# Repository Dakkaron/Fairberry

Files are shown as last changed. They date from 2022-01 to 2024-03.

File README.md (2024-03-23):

# Fairberry

The goal of this project is to add a BlackBerry Q10 keyboard to non-BlackBerry phones. While this can easily be adapted to suit any other phone with an USB port at the bottom, I will focus on releasing files for the Fairphone 4, since that is what I have. Feel free to adjust it to your phone and share your results in the discussion area.

The Fairberry keyboard is detachable and can be used without any modifications on the phone. Since it connects over USB, there is no need for separate batteries or glitchy Bluetooth connections.

## What can you expect?

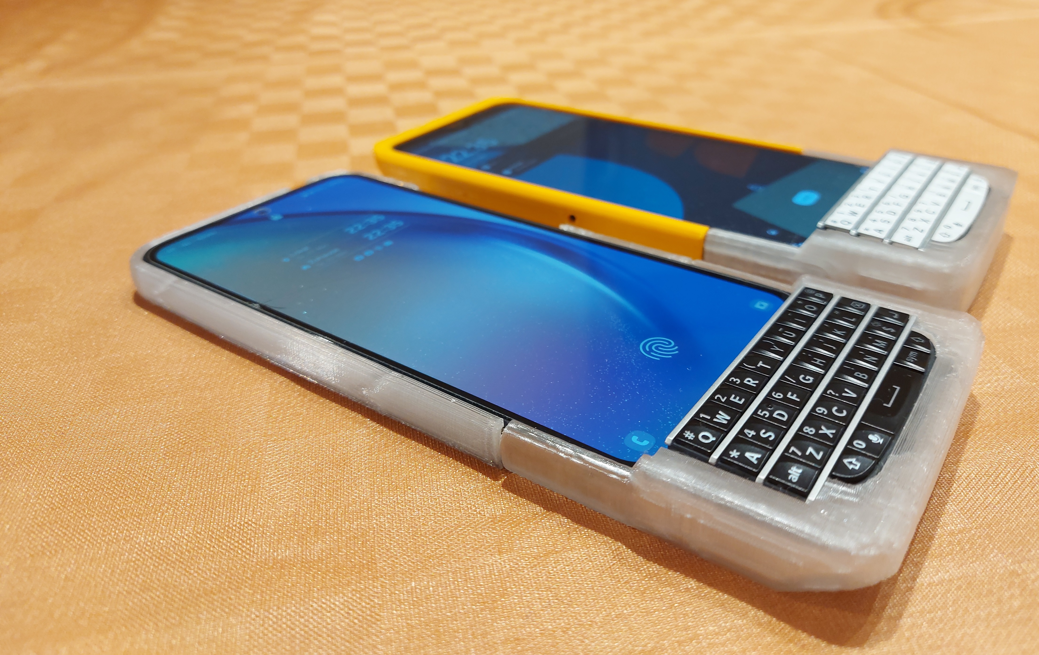
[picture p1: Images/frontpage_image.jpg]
Samsung Galaxy A54 and Fairphone 4 with Fairberry keyboards


### Demo video
Demo video showing the functionality of the Fairberry keyboard (https://www.youtube.com/watch?v=iDb8_ld9gOQ)

## How to build it?

Recommended: [Custom mainboard](https://github.com/Dakkaron/Fairberry/blob/main/Documentation/Hardware_Fairberry_Mainboard.md)

[Old Arduino-based hardware](https://github.com/Dakkaron/Fairberry/blob/main/Documentation/Hardware_Arduinobased.md)

## How to use it?

[Key combinations and apps](https://github.com/Dakkaron/Fairberry/blob/main/Documentation/UX_Shortcuts_and_Apps.md)

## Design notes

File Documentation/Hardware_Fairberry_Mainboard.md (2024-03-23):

# Bill of Materials

- Blackberry Q10 replacement keyboard
- Assembled mainboard from JLCPCB
- Solderable USB 2.0 OTG connector (can be USB C, Micro USB or even Lightning)
- Thin wires to connect the USB board to the PCB (The thinner the better)
- 6 Pin headers
- USBASP Programmer
- Jumper wires

# Ordering from JLCPCB

## Downloads

First go to the release page (https://github.com/Dakkaron/Fairberry/releases) and locate the newest release.

Download gerber-*.zip, BOM.xlsx and CPL.xlsx.

## Order Hirose Keyboard Connector

JLCPCB does not usually stock the keyboard connector (Hirose BM14B(0.8)-24DS-0.4V(53)). To get them to include this part in the assembly, you first need to order the part in their part sourcing programme. To do so:

- Head to the part ordering page: https://jlcpcb.com/parts
- Log in to your JLCPCB account (create one if you don't have one)
- At the part ordering page, search for this part: HRS(Hirose) BM14B(0.8)-24DS-0.4V(53)
- There should be one result. Select it, choose an amount (2 or multiples of 5) and then press "Add to My Part Lib" and follow the order process
- Sourcing the components will take a few weeks
- Once they sourced the parts, they will refund you the difference between what you paid and what JLCPCB paid to the part seller, so it will likely be a bit cheaper than what you paid up front

## Order PCB

- Head to the JLCPCB PCB ordering page: https://cart.jlcpcb.com/quote?orderType=1&stencilLayer=2&stencilWidth=100&stencilLength=100&stencilCounts=5
- Upload the gerber-*.zip file. You can leave everything in the main box on default.
- Scroll down until you find "PCB Assembly" and activate that.
- Depending on how many parts you want to order, select 2 or 5 under "PCB Assembly". Ordering more parts will be cheaper per part. Please note, you will receive 5 boards regardless, but only the selected amount will be populated (will have components soldered to it).
- Press "Next".

## BOM and CPL

On the following page, upload the BOM.xmlx and the CPL.xmlx. On the dropdown on the bottom of the page select "Office Appliance and Accessories" -> "Keyboard".

Press "Next" again.

## Component list

You should now see a list of components. Verify that no errors (e.g. "Component out of stock") are displayed and all parts are selected. You should be able to take the Hirose connector from your part library.

Press "Next" again.

## Component placement

The next page shows a rendering of the component placement. Verify (multiple times) that the image looks exactly as the image below. Especially all the pink markings need to be exactly the same.

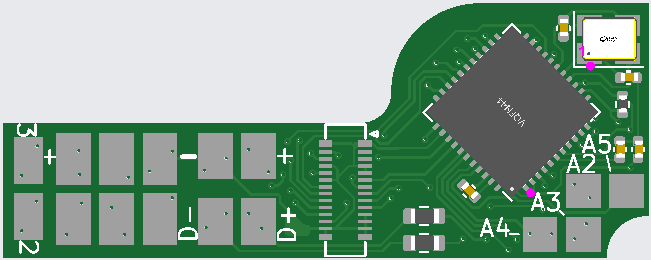
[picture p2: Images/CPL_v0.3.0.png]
Component placement image


If one of the parts is rotated wrong (indicated by the pink markings being in the wrong location), select the component and use the "All Rotate Right/Left" buttons at the top to fix it.

If you are really sure it looks the same, press "Save to cart" and procede with ordering the PCB.

# Remaining Assembly

Solder the programming headers like in the picture below. These pin headers are only required for initial flashing, and can be desoldered afterwards, as they won't be needed anymore.

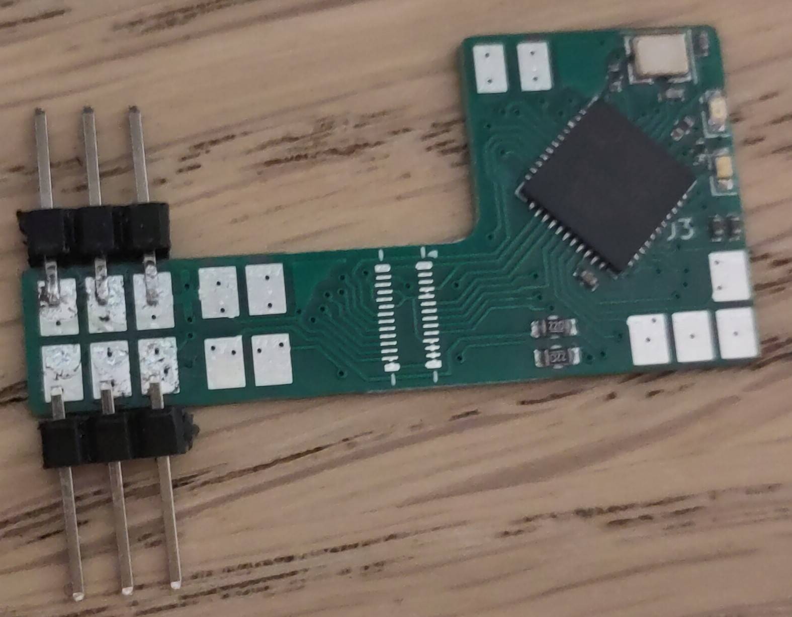
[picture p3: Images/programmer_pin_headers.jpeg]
Placement of programming pin headers


Now take your USBASP and some jumper wires and connect the headers to the fitting pins on the programmer, following the images below. The pinout of the USBASP is shown here as viewed into the connector, with no cable plugged in.

Make sure you are using pinout for the right mainboard version.

## USBASP
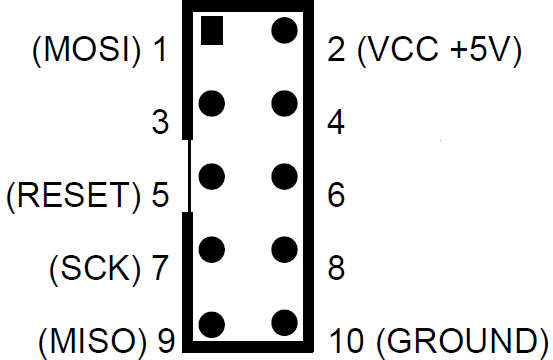
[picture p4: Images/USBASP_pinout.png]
USBASP pinout


## v0.1.1
![]()
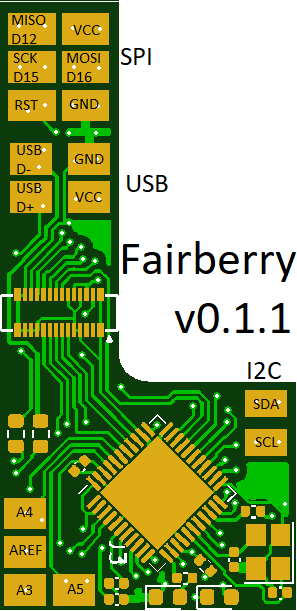
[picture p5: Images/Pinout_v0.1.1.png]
Fairberry v0.1.1 pinout


## v0.2.0
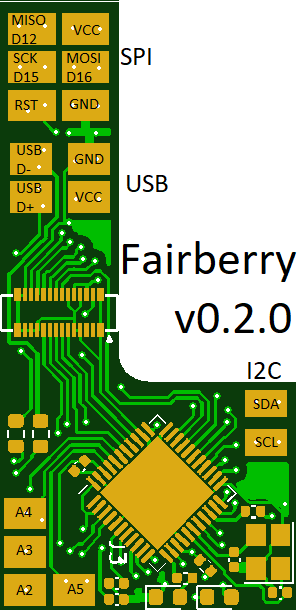
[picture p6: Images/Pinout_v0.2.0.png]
Fairberry v0.2.0 pinout


## v0.3.0
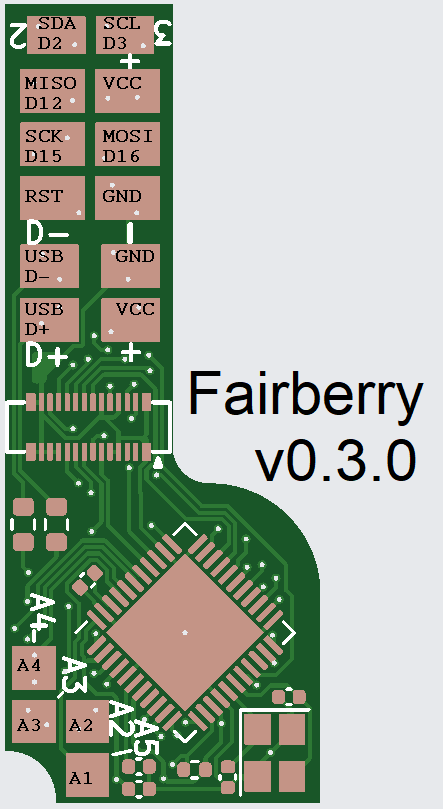
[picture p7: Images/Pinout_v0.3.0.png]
Fairberry v0.3.0 pinout


Now solder the USB connector to the USB port on the Fairberry mainboard. Take care to get the pinout right and not cause any shorts.

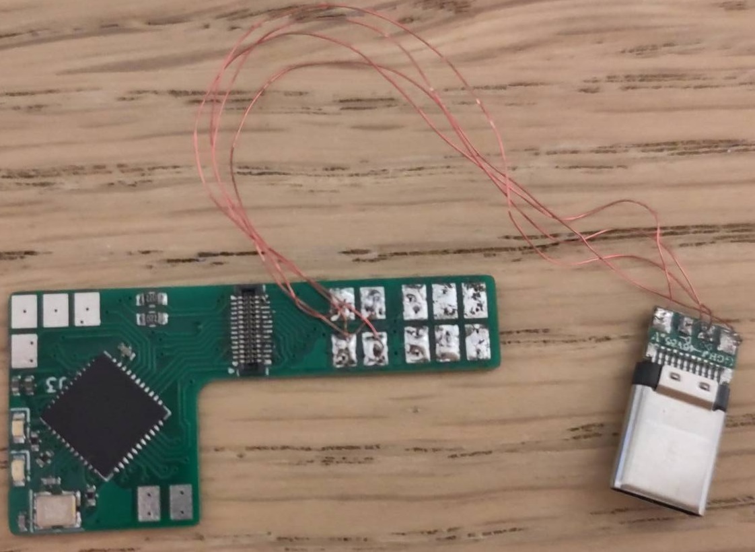
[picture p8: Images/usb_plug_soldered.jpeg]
Fairberry v0.1.1 with USB connector


# Flashing the firmware

## Flashing the bootloader

This step only needs to be done once. After you flashed the bootloader, you can update the firmware over the USB connector.

Download and install the [Arduino IDE](https://www.arduino.cc/en/software).

Open the Arduino IDE.

Connect the USBASP with the connected Fairberry Mainboard to a USB port of the computer.

WARNING: DO NOT PLUG THE USB CONNECTOR OF THE FAIRBERRY INTO THE PC, WHILE THE USBASP IS CONNECTED!

In the Arduino IDE, select "Tools" -> "Board" -> "Arduino AVR Boards" -> "Arduino Leonardo". Then select "Tools" -> "Burn Bootloader".

This will take a while. Wait until it finishes. If there are errors, check your solder joints and the wires connecting the Fairberry to the USBASP.

Once this is done, disconnect the Fairberry from the USBASP. You can now desolder the header pins.

## Flashing the firmware

Head to the [releases page](https://github.com/Dakkaron/Fairberry/releases), download and unzip the file BBQ10_Arduino_sources.zip.

Open the BBQ10.ino in the Arduino IDE.

In the Arduino IDE select "Tools" -> "Manage Libraries".

In the Library Manager, check that the following libraries are installed (and install them if they aren't):

- Keyboard, by Arduino, version 1.0.4 or newer
- LowPower_LowPowerLab, by LowPowerLab, version 2.2.0 or newer.

Now close the Library Manager.

Open the file configuration.h in the Arduino IDE.

Find this line

    #define BOARD_TYPE FAIRBERRY_V0_3_0

and adjust the board type to the version that you are using.

Make sure the USBASP is disconnected from the PC and the Fairberry Mainboard.

Connect the Fairberry Mainboard's USB connector to the PC.

Select "Sketch" -> "Upload" and wait for the upload to finish.

If you get an error, verify your soldering.

# Testing

Now you are basically done. To test the mainboard, connect the Blackberry Q10 keyboard to the connector and plug the whole thing into the USB/Lightning port of your phone. Open some app where you can type and check if every key works as expected.

## Troubleshooting

If some keys work but others don't, some of the pins on the Hirose connector aren't soldered correctly. To figure out which ones, check out this [Column to row key matrix](https://github.com/arturo182/BBQ10KBD#columnrow-to-key-matrix).  With this you can figure out, which rows/colums have bad contacts.

Now look at this [breakout adapter](https://github.com/arturo182/bbq10kbd_breakout) and follow the traces from the defective row/column pin to the pin on the connector to figure out, which pin has a bad contact.

If you know which pin is at fault, try to carefully solder it on with a fine-tipped soldering iron.

## Generating the 3D-print file for the case

### Prerequisites
- Install [OpenSCAD](https://openscad.org/)
- Download and extract the Source Code zip file from [the newest release](https://github.com/Dakkaron/Fairberry/releases)
- Open `Fairberry-x.x.x/Case/Generator/Fairberry.scad` in OpenSCAD

### Customizing
- In the `Fairberry.scad` script, set the `SCREEN_PROTECTOR_HEIGHT` to the thickness of your screen protector. If you don't use one, set it to `0`.
- Set the `EXTRUSION_WIDTH` to the extrusion width of your 3D printer. For 0.4mm nozzles, it's usually 0.48. If you use a resin printer, leave it at 0.4.
- If you are using a Fairphone 4 or a Samsung Galaxy A54, comment out the line `include <presets/Custom.scad>` by placing a double slash (`//`) at the beginning of the line, and uncomment the line fitting your phone. You can skip the rest of the customization.
- If you are using a different phone, open up `Fairberry-x.x.x/Case/Generator/presets/Custom.scad` in OpenSCAD and customize the values in there to your liking. To preview the changes, save your changes in the `Custom.scad` and then open up `Fairberry.scad` in OpenSCAD and press F5 to generate a preview.
- When using `Custom.scad`, it is recommended to find a dummy STL of your phone. [Yeggi.com](https://www.yeggi.com/) and [Grabcad](https://grabcad.com/) are good sources for dummy phone models.

### Generating the file
- Once everything is customized to your liking, open `Fairberry.scad` and press F5 to generate a preview.
- Press F6 to render the file (this may take multiple minutes depending on your hardware).
- Press F7 and save the resulting STL file as `Fairberry.stl`.

## Printing the case

You need to print two files: The `Fairberry.stl` you generated in the last step and the `Fairberry-x.x.x/Case/Generator/USB_Clamp.stl`.

If you don't own a 3D printer, [JLCPCB](https://jlc3dp.com/3d-printing-quote) is a good place to start.

## Assembly

First secure the flex PCB of the keyboard with a bit of kepton tape. This is done to reduce the risk of ripping the flex PCB at the point where it enters the keyboard.

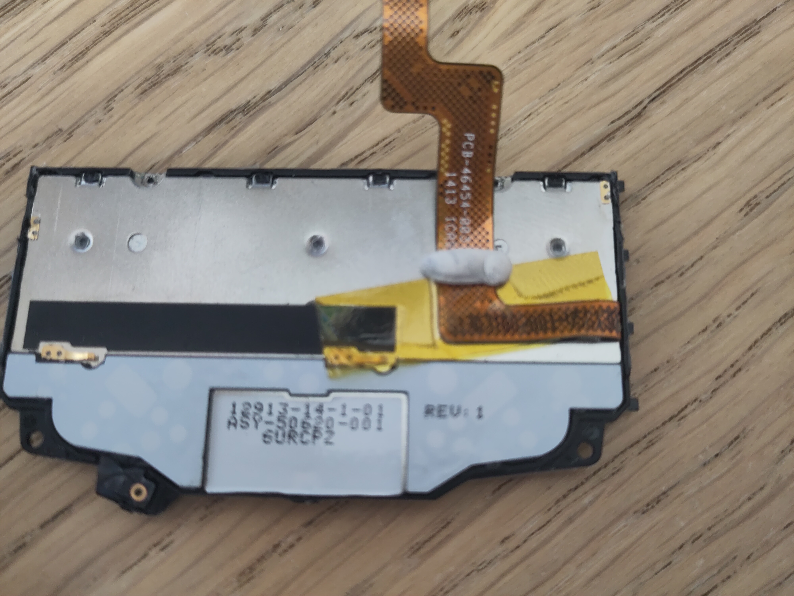
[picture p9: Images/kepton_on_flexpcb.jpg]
Kepton on flex PCB


Next put a small roll of Blu-Tack/Patafix onto the flex PCB and CAREFULLY bend it, like in the picture below. Warning, bending needs to be done carefully, otherwise it can break. Don't bend it more often than necessary. The roll of Blu-Tack/Patafix is there to cushion the bend a bit, so that it doesn't have as much strain on it.

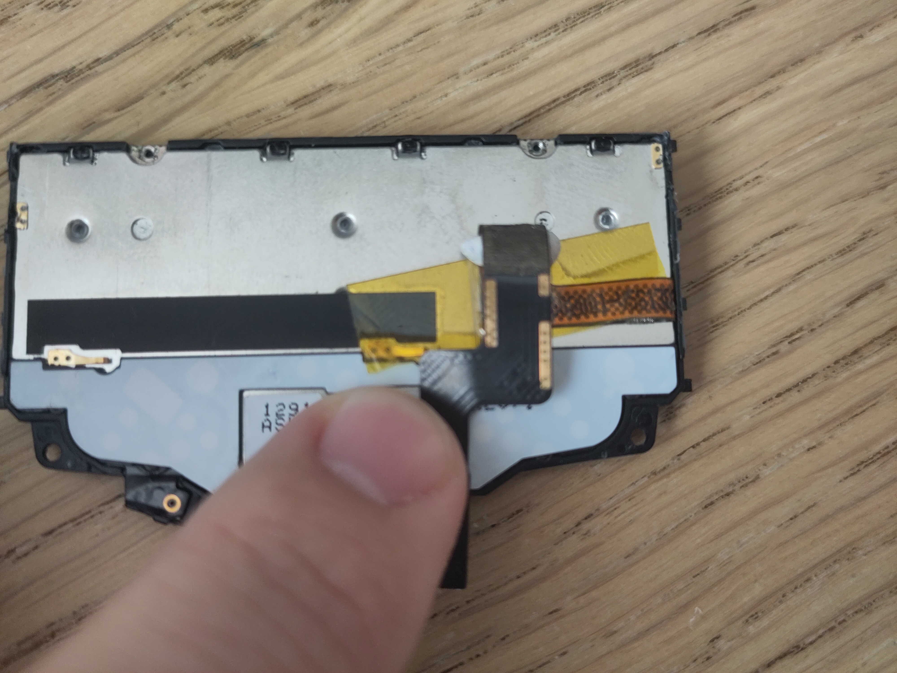
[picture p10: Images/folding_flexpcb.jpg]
Folding flex PCB


Optionally you can wrap the mainboard in kepton tape. This reduces the risk for shorts and keeps it clean from Blu-Tack/Patafix. Make sure to keep the keyboard connector free of kepton.

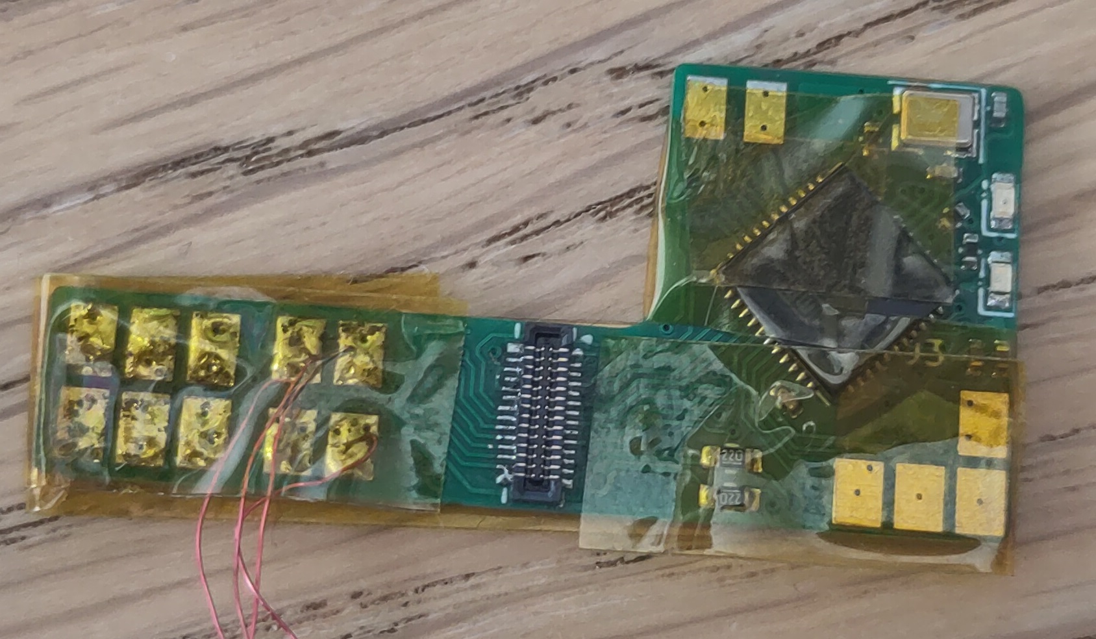
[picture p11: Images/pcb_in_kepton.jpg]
Mainboard wrapped in kepton


Put some thin blobs of Blu-Tack/Patafix onto the backside of the mainboard and plug the keyboard's flex PCB into the mainboard.

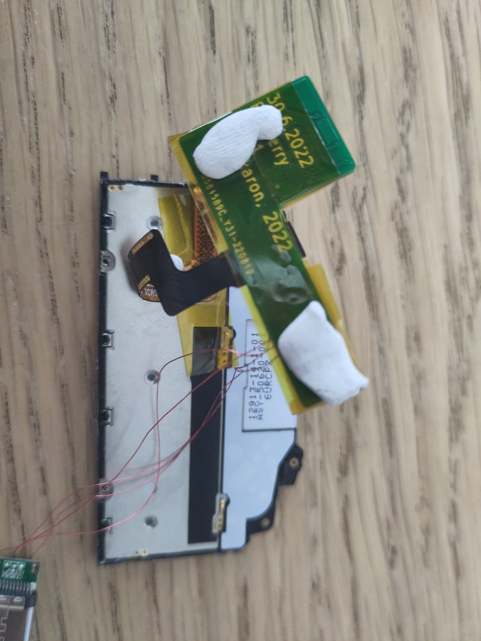
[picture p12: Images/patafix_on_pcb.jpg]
Patafix on mainboard


Carefully bend the Flex PCB into an S-shape under the mainboard and very carefully press the mainboard onto the keyboard, so that the Blu-Tack/Patafix can stick to the keyboard. Optionally, you can now also put a strip of kepton over the keyboard connector, to secure it to the mainboard.

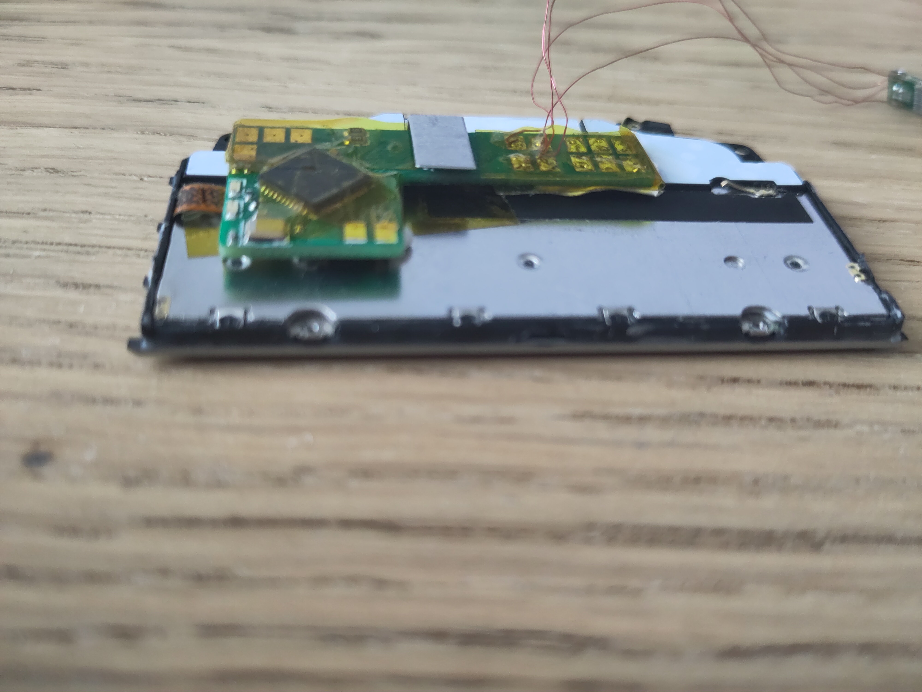
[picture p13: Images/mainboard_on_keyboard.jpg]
Mainboard on keyboard


Put the M3 screws through the hole in the case and place the USB connector into the fitting hole.

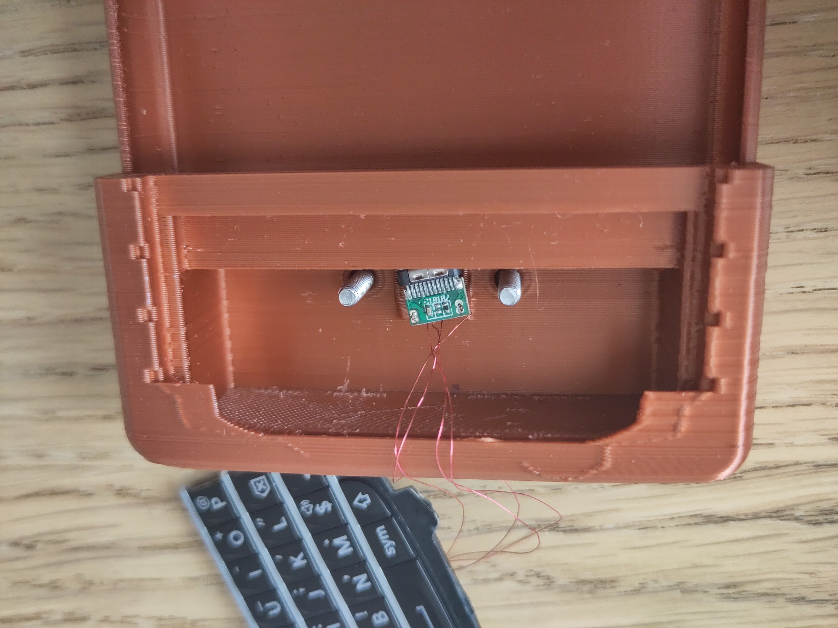
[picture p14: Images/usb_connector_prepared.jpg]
Preparing USB connector


Put the M3 nuts into the holes in the USB clamp and screw it down. To help aligining the USB connector, place your phone into the attachment and plug the USB connector into the phone, before screwing it down. This makes sure that the USB corrector is aligned correctly.
Also put a thin roll of Blu-Tack/Patafix on the top part of the area where the keyboard goes.

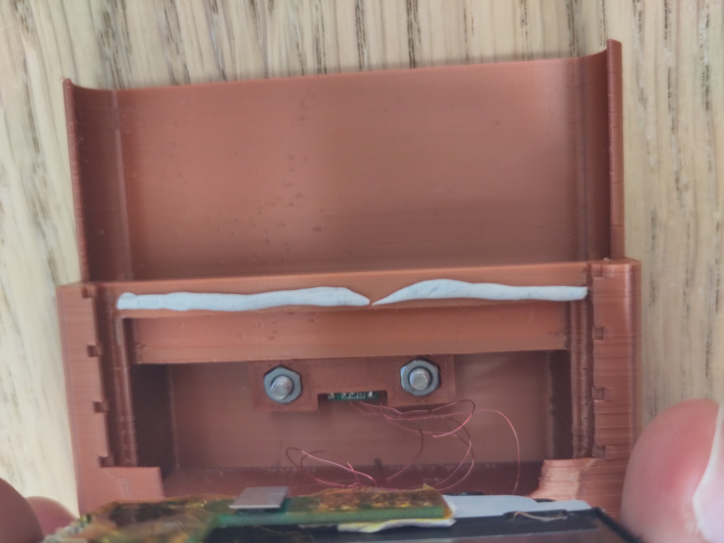
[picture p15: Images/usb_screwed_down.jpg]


Lastly, hook the bottom lip of the keyboard into the fitting hole in the case and carefully slide it in at an angle from the top. It might take a bit of careful force to put it in.

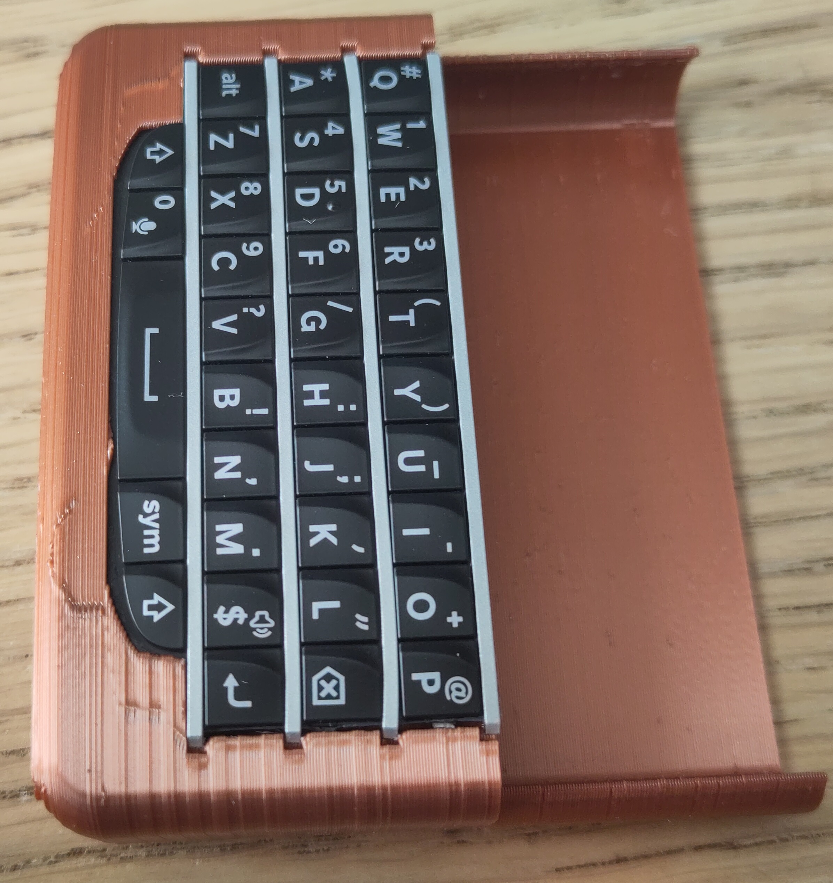
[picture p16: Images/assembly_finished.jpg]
Fully assembled attachment


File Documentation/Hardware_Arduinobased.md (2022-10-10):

# This information is outdated. The newer hardware version can be found [here](https://github.com/Dakkaron/Fairberry/blob/main/Documentation/Hardware_Fairberry_Mainboard.md)

## How is it working?

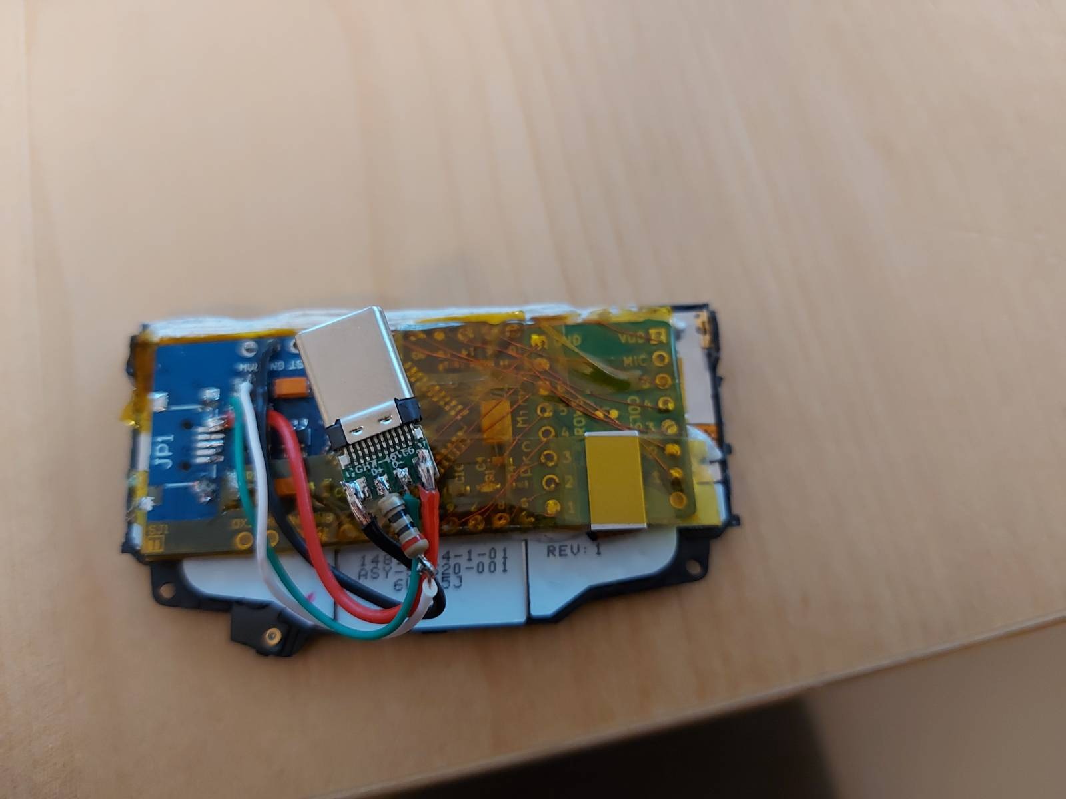
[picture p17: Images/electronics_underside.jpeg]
Underside of the electronics

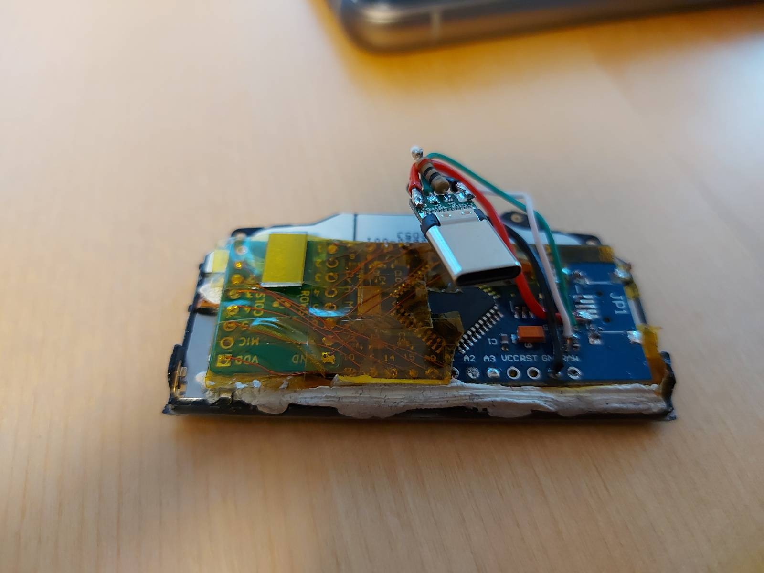
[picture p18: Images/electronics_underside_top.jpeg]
Other angle of the underside of the electronics


There are five parts to the Fairberry keyboard:

- A BlackBerry Q10 replacement keyboard from Aliexpress (~€10-15 plus shipping)
- The BlackBerry Q10 Keyboard Breakout Board from here: https://github.com/arturo182/bbq10kbd_breakout
- An Arduino Pro Micro (Micro, not Mini! This is very important since the Pro Mini does not have USB interface that can be used to emulate a keyboard!)
- An USB C or Micro USB OTG breakout board or cable to connect to the phone
- The 3D printed case

> :warning: **Please read (and understand) the whole page before buying/building it!**

> :warning: **Messing this up can result in damage to your phone, your PC and/or the parts used in this build. If you are new to soldering, ask someone for help! I am not responsible for any damage that you do to your stuff! You are doing this at your own risk!**

### The BlackBerry Q10 Keyboard

This is just a regular keyboard for the BBQ10. You can either buy a replacement one from eBay or Aliexpress, or scavenge one off a BlackBerry Q10. Better get multiple ones, if shipping is slow. The flex PCB needs to be bent and can break in this process.

I decided to use the Q10's keyboard (and not, for example, the Key1/Key2 keyboard) since the Q10 keyboard is documented really nicely, and there are ready-made adapter designs, that I could use without having to design my own PCB.

I took the US Keyboard layout, since it was the easiest to get. If you get another keyboard layout you will need to adjust the keyboard mapping in the Arduino sketch.

### The BlackBerry Q10 Breakout Board

You can get the breakout board design files from here: https://github.com/arturo182/bbq10kbd_breakout

To get the board printed, you need to download the bbq10kbd_breakout repository files ("Code" -> "Download ZIP"). Next, put all files in the folder named "gerber" in a zip file and upload it here: https://jlcpcb.com/

The minimum order quantity at JLCPCB is 5. It is not a mistake to order more, this part is really tricky to solder. If you haven't soldered small SMD components before, you will need a few tries.

You also need to buy some Hirose BM14B(0.8)-24DS-0.4V(53) connectors. They are a bit hard to get. One place to get them from is https://www.mouser.at/ProductDetail/Hirose-Connector/BM14B08-24DS-04V53?qs=QRVci0nWsCaR3TeKMbLD%252Bw%3D%3D

Also here, get a few of them. You are going to need them.

Once you have those parts, the connector needs to be soldered to the board.

If you don't feel comfortable soldering something that tiny, go to your local phone/laptop repair shop. They usually have the equipment and skill to solder something like that for a few Euros.

If you've done that, that was the trickiest part.

Make sure you verify with a multimeter that all the conenctions are working and there are no shorts.

### The Arduino Pro Micro

Make sure you get an Arduino Pro Micro, and not the Pro Mini. The Pro Mini uses a different chip that doesn't natively support USB, and it will not work. To work, your Pro Micro should have an AtMega32u4 chip on it. It doesn't matter too much what kind of USB connector is on there, since we are going to remove that one anyways.

First, flash the BBQ10.ino sketch to your Arduino. For that, download the BBQ10 folder in this repository, download the Arduino IDE, and open the BBQ10.ino in the Arduino IDE.

Next, select "Tools" -> "Board" -> "Arduino Leonardo".
Now select "Tools" -> "Port" and note down all ports listed there (if there are any)
Then connect the Arduino to the PC using an USB cable, and recheck "Tools" -> "Port" for the new port that should have appeared. Select that port.
Now you can flash the sketch to the Arduino using "Sketch" -> "Upload".

You can now desolder the USB socket from the Arduino.

### The USB connector

Depending on your phone, get an USB C or Micro USB connector. You can either use OTG Breakout Boards (they give really good results, since they are very small) or USB 2.0 OTG cables (they are easier to find and easier to work with). What you choose is up to you.

If you got a cable, cut it about 5 cm from the connector. Strip about 2 cm of the outer plastic and shielding. Cut off any bare wires, so that there are only four cables left over. These should be red (5V), black (GND), green (Data-) and white (Data+). Strip the ends of the four cables and spread them apart. Make sure they don't touch. Now plug them into your phone and, using a multimeter in voltage mode, touch the red and black wires with the respective colored leads on the multimeter. Check that the multimeter displays 5V. If it doesn't, throw away the cable and get a new one. The reason is, that there are some extremely cheaply made USB C cables with wrong wireing. One of these cables might fry your keyboard and/or your phone. Make sure, you detach the cable from the phone when you are done. Shorting these cables while connected to your phone could also fry your phone.

### The Case

The cases are still work in progress.

The cases are plug-and-play, so you can easily replace the case at a later date, without having to change anything about the electronics.

Currently, there are two options: A bottom-only case (which is what is shown in the pictures above) and a full-body multimaterial case. For the multimaterial case you need a 3D printer capable of handling two different materials at the same time (e.g. by having two extruders). Also, the printer needs to be able to handle flexible materials.

The files for the cases are in the Cases-folder of this repository.

Print files with _PLA in the name in any hard plastic of your choice (PLA, PETG, ABS, ...). Any will work.

Print files with _TPU in the name in any flexible plastic of your choice (TPU, TPE). A bit harder might be better, but since I have only used one type of flexible filament (FlexiSmart), your milage may vary.

## Assembling all the parts

Assembly is a bit tricky. You will need either some double-sided tape or (what I used) some putty-like adhesive (e.g. Blu Tack or Patafix).

First, take the connector and the Arduino. Put them next to each other in the orientation shown on the following image:
Underside of the electronics

Using some thin enameled wire and solder, connect the pins like in the following table:

| Adapter | Arduino |
| --- | --- |
| Row 1 | 9 |
| Row 2 | 8 |
| Row 3 | 7 |
| Row 4 | 6 |
| Row 5 | 5 |
| Row 6 | 4 |
| Row 7 | A2 |
| Col 1 | A1 |
| Col 2 | A0 |
| Col 3 | 15 |
| Col 4 | 14 |
| Col 5 | 16 |
| GND | GND (I used the one next to Pin 2) |
| VCC | 10 (Used for the backlight) |

Do not connect the MIC or the unlabelled connector on the bottom right of the adapter.

The next step is to solder the USB connector to the Pro Micro. In the image you can see a small resistor at D+. You will not need that one. My Arduino had a defective resistor, and this is just overriding it. So, just ignore that resistor.
The following image shows where each of the USB connector's leads need to be soldered to:
Underside of the electronics

Now take the BlackBerry Q10 keyboard, and put it face down. Check the picture below for the finished assembly positions:

Next, take some Blu Tack/Pattafix/... and put a small bit on the keyboard, where the Arduino will come to rest. You will now have to bend the flex PCB in an S shape. Make sure you don't fold the PCB, since that might break it. Put some 1-2mm thick ropes of Blu Tack/Pattafix in the bends to make sure they don't fold. Connect the connector to your adapter. Make the S bend and stick the electronics down with a thin layer of Blu Tack/Pattafix.

The keyboard itself is now ready. You can connect it to a smartphone or keyboard and see if all keys work. You will need to set the keyboard layout on your device to standard (no layouts activated) if you get incorrect output. This is necessary, because Android 11 has a bug that distorts all other layouts if an accessibility service is activated.

If everything is working, it's now time to attach the keyboard to your phone.

Put a thin roll of Blu Tack/Pattafix at the top rim of the keyboard. This is used to stick the keyboard to the case. Slide the keyboard from the top into the recess at the bottom of the keyboard, and fold it down.

Your keyboard is now ready to be used!

## Android adjustments:

If the keyboard overlaps too much with your screen, install adb on your PC and enable Developer Options on your phone. Connect the phone to the PC and open a shell window (under Windows cmd, under Linux/MacOS use bash or whatever you have) and execute the following command:

```
adb shell wm size
```

This shows the current resolution of the smartphone. Now reduce the second number by doing this:

```
adb shell wm size 1080x2200
```

You will have to figure out what resolution you want to use, so just try out which values fit for you.
To reset it to default, execute this command:

```
adb shell wm size reset
```

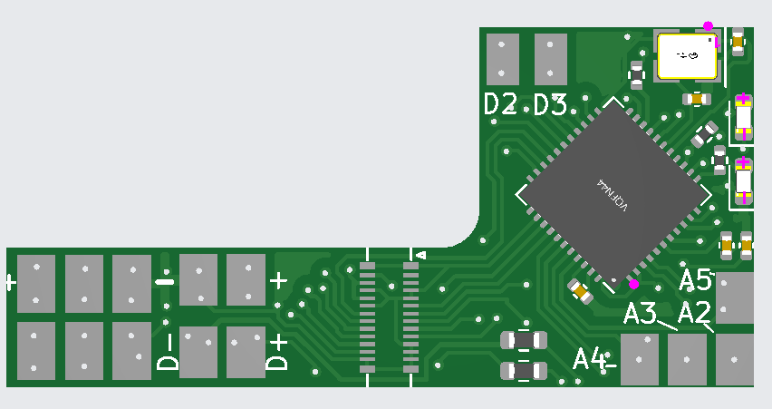
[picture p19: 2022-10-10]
Images/CPL_v0.2.0.png

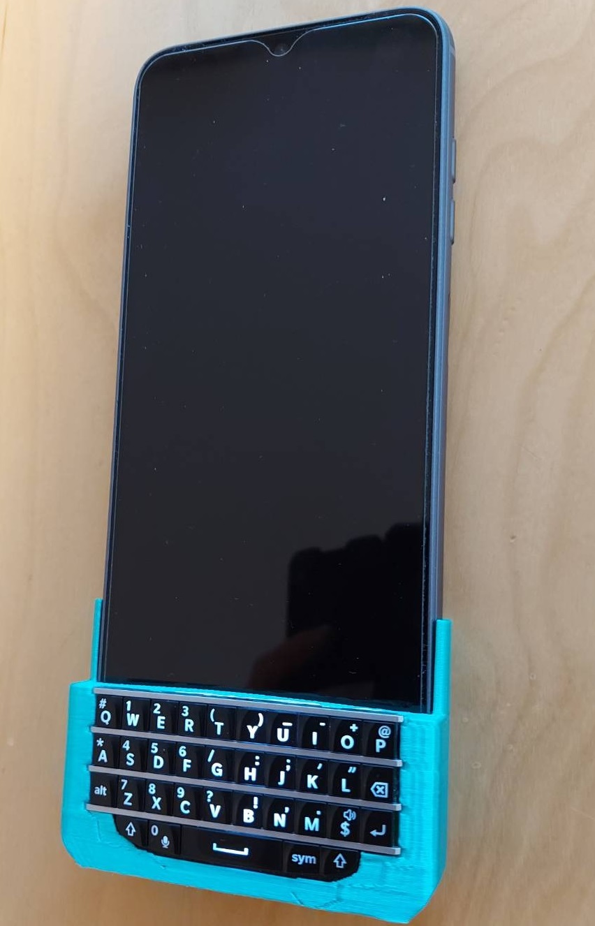
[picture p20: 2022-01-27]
Images/keyboard_attached_top.jpeg

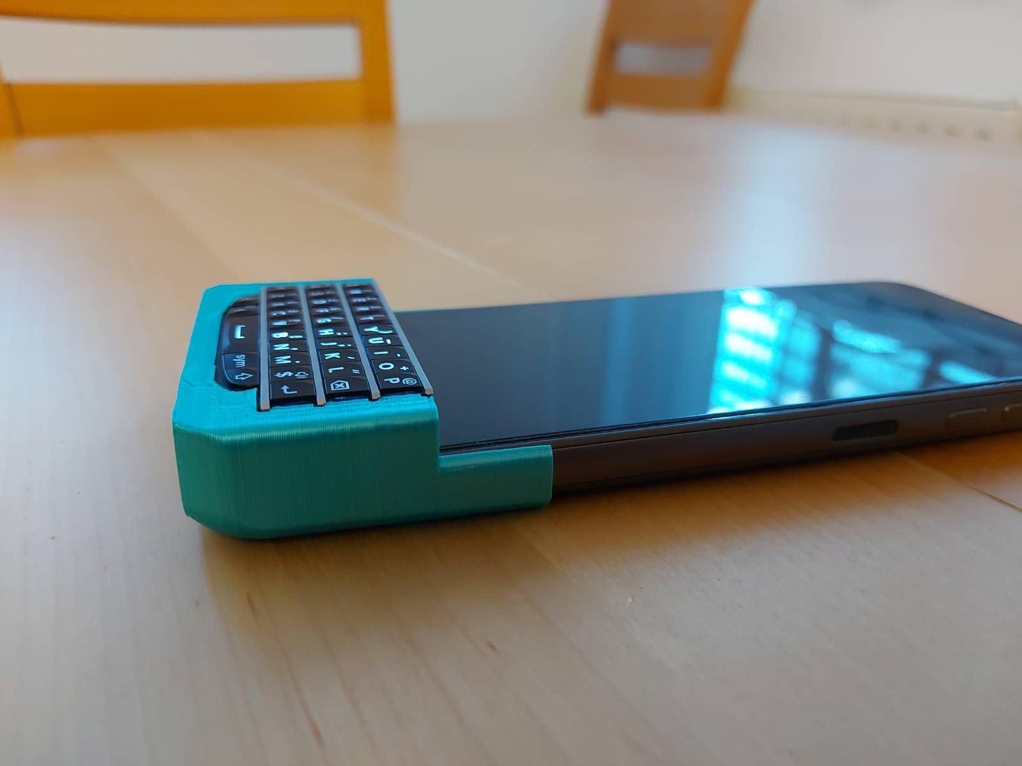
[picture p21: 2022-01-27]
Images/keyboard_attached_side.jpeg

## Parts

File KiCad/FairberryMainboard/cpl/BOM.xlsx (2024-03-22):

Comment | Designator | Footprint | JLCPCB Part #（optional）
ATMEGA32U4-MU | U1 | QFN-44_EP_7.0x7.0x0.5P | C112161
±1% 1/10W Thick Film Resistors 75V ±100ppm/℃ -55℃~+155℃ 22Ω 0603 Chip Resistor - Surface Mount ROHS | R2,R3 | 0603 | C23345
1/16W Thick Film Resistors 50V ±1% ±100ppm/℃ -55℃~+155℃ 10kΩ 0402 Chip Resistor - Surface Mount ROHS Copy | R1 | 0402 | C25744
25V 1uF X5R ±10% 0402 Multilayer Ceramic Capacitors MLCC - SMD/SMT ROHS | C1 | 0402 | C52923
50V 22pF C0G ±5% 0402 Multilayer Ceramic Capacitors MLCC - SMD/SMT ROHS | C4,C5 | 0402 | C1555
16MHz SMD Crystal Resonator 9pF ±10ppm ±30ppm -40℃~+85℃ SMD3225-4P Crystals ROHS | Y1 | SMD-CRY-3225_4P | C13738
16V 100nF X7R ±10% 0402 Multilayer Ceramic Capacitors MLCC - SMD/SMT ROHS | C2,C3 | 0402 | C1525
0.4mm 2 24P Brick nogging Female SMD,P=0.4mm Mezzanine Connectors (Board to Board) ROHS | U2 | SMD,P=0.4mm | C3640874

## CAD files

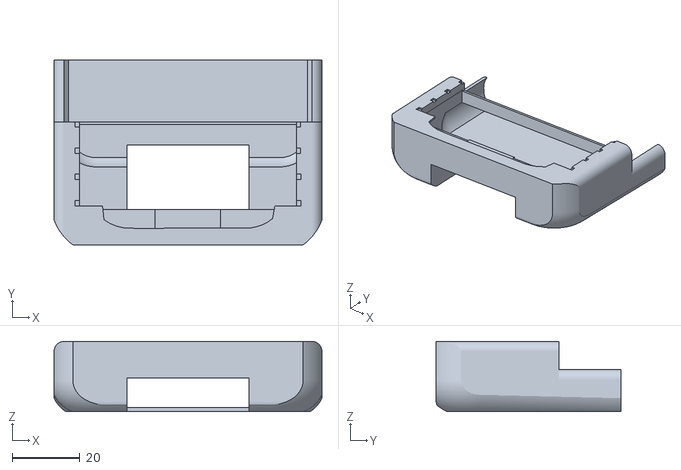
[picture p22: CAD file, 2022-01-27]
Case/Fairphone4/Bottom-Only-Case/BottomOnlyCase_PLA.stl
79.0 x 54.4 x 20.7

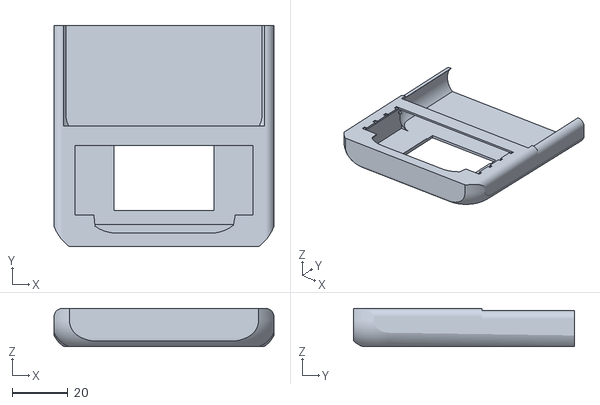
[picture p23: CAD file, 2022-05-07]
Case/Fairphone4/Flat-Case/flatCase.stl
79.0 x 79.5 x 13.7

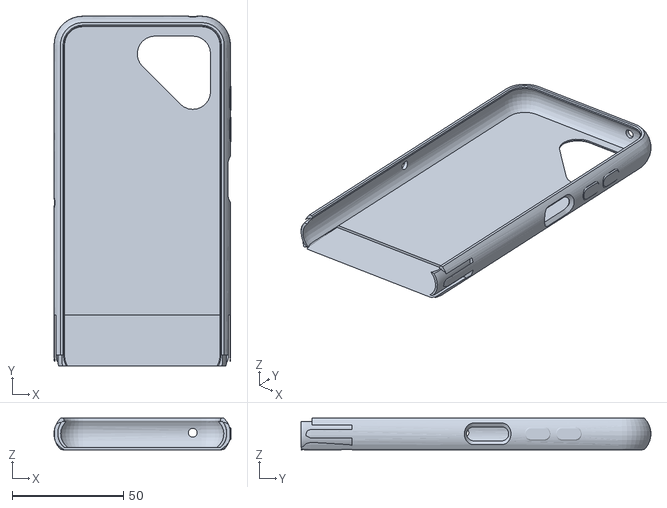
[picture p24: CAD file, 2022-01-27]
Case/Fairphone4/Two-Material-Case/TwoMaterialCase_TPU.stl
79.7 x 157.5 x 14.2

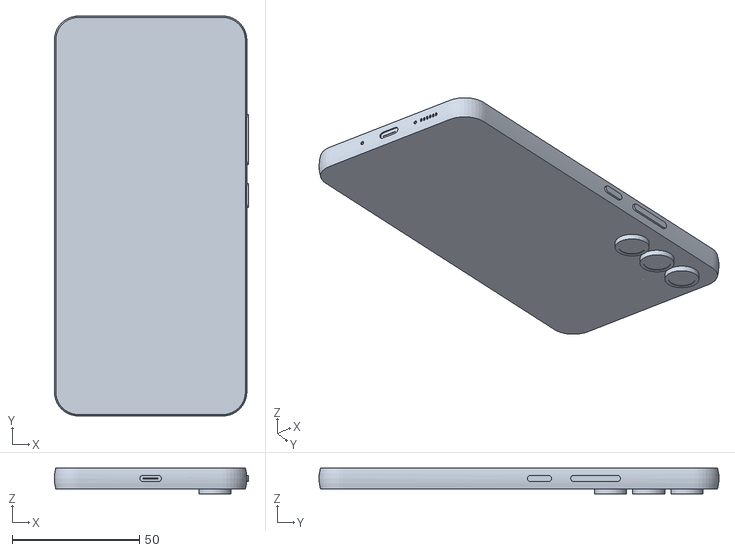
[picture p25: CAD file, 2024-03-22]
Case/Generator/import/A54_Dummy.stl
76.3 x 157.1 x 10.2

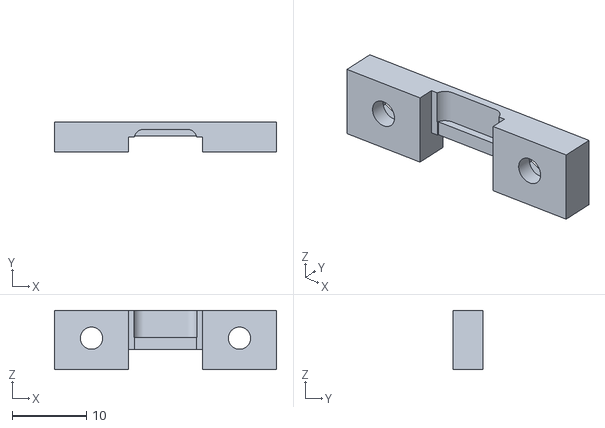
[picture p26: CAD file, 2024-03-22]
Case/Generator/USB_Clamp.stl
30.0 x 4.00 x 8.00

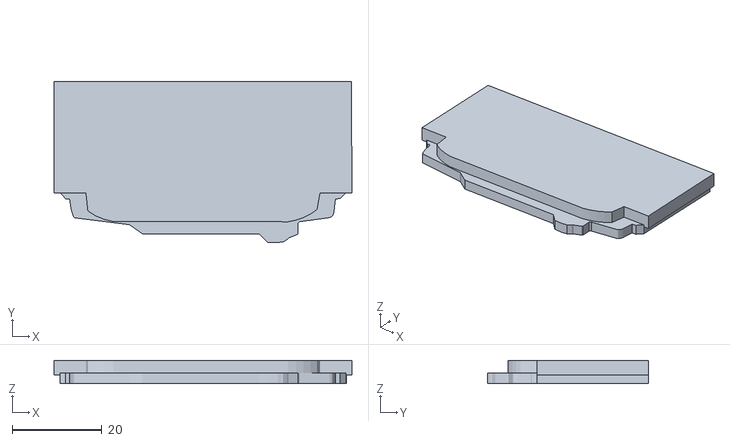
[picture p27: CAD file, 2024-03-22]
Case/Generator/import/BBQ10KBD.stl
66.6 x 36.0 x 5.23

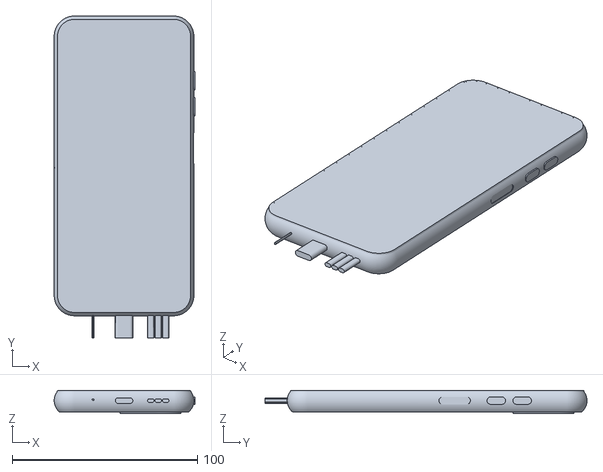
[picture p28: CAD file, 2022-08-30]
Case/Generator/import/FP4_Dummy_Screenprotector.stl
76.0 x 174.0 x 12.6

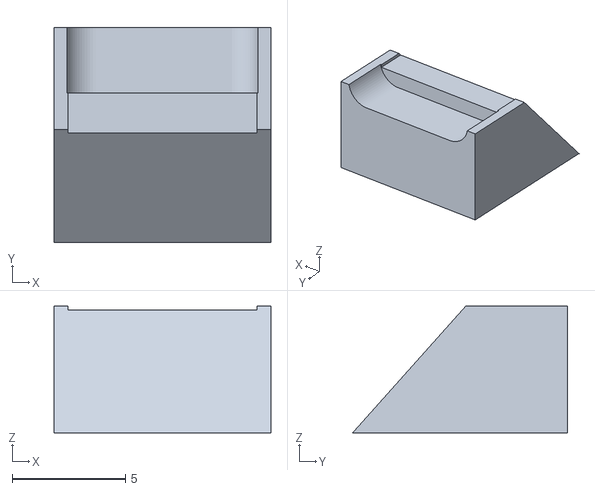
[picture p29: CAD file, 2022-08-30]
Case/Generator/import/USB_Anvil.stl
9.60 x 9.50 x 5.60

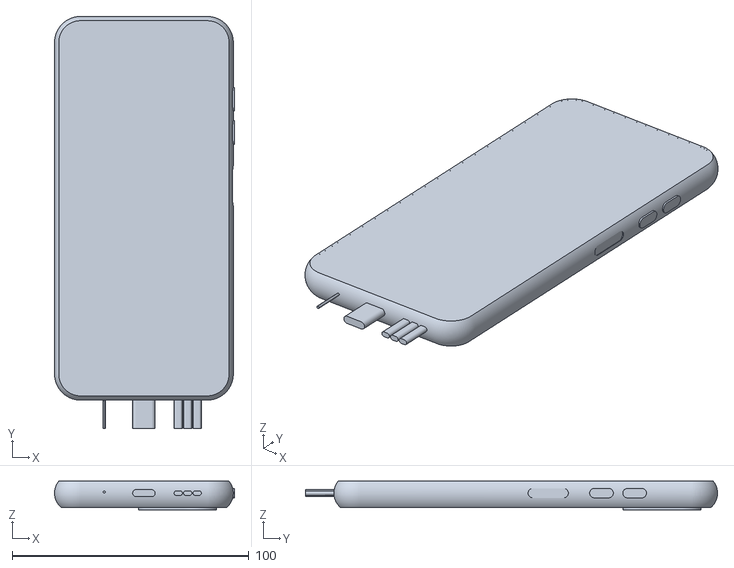
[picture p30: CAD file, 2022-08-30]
Case/Generator/import/FP4_Dummy.stl
76.0 x 174.0 x 12.1

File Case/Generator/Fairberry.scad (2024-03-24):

// Fairberry Keyboard Case Generator © 2024 by Dakkaron is licensed under Attribution-NonCommercial-ShareAlike 4.0 International.
// To view a copy of this license, visit http://creativecommons.org/licenses/by-nc-sa/4.0/
// Version 2

SCREEN_PROTECTOR_HEIGHT=0.6; // Thickness of the screen protector
EXTRUSION_WIDTH=0.48; // Extrusion width of your 3D printer

// Uncomment the type of phone you use. If your phone doesn't appear in this list, leave "include <presets/Custom.scad>" and edit the file at presets/Custom.scad to fit your phone.
include <presets/Custom.scad>
//include <presets/SamsungGalaxyA54.scad>
//include <presets/Fairphone4.scad>


_KEYBOARD_CATCH_DEPTH=1.5;
_ELECTRONICS_CUTAWAY_TOP_CLEARANCE=5;
_ELECTRONICS_BAY_TOPWALL_THICKNESS=0.5;
_ELECTRONICS_CUTAWAY_WIDTH=60.0;
_ELECTRONICS_CUTAWAY_BACKWALL_EXTRAPERIMETERS=5;
_ELECTRONICS_CUTAWAY_THICKNESS=PHONE_THICKNESS+SCREEN_PROTECTOR_HEIGHT+KEYBOARD_PHONE_GAP_PERIMETERS*EXTRUSION_WIDTH-_ELECTRONICS_CUTAWAY_BACKWALL_EXTRAPERIMETERS*EXTRUSION_WIDTH;
_ELECTRONICS_CUTAWAY_LENGTH=25;
_KEYBOARD_THICKNESS=3.6;
_CASE_BOTTOM_LENGTH=38;
_CASE_KEYBOARD_Y_OVERLAP=EXTRUSION_WIDTH*2;

_USB_PORT_CUTAWAY_WIDTH=10;
_USB_PORT_CUTAWAY_HEIGHT=3.5;
_USB_PORT_CUTAWAY_LENGTH=20;
_USB_PORT_ROUNDING_RADIUS=2;

//Case cannot get smaller than 70mm, due to keyboard width
CASE_WIDTH=max(PHONE_WIDTH, 70.0) + EXTRUSION_WIDTH*PERIMETERS*2;
CASE_THICKNESS=PHONE_THICKNESS + EXTRUSION_WIDTH*CASE_BOTTOM_PERIMETERS + _KEYBOARD_THICKNESS + SCREEN_PROTECTOR_HEIGHT + KEYBOARD_PHONE_GAP_PERIMETERS*EXTRUSION_WIDTH;

assert(CASE_ROUNDING_RADIUS*2<PHONE_THICKNESS+2*CASE_BOTTOM_PERIMETERS*EXTRUSION_WIDTH, "Error: CASE_ROUNDING_RADIUS needs to be smaller than PHONE_THICKNESS + 2*CASE_BOTTOM_PERIMETERS*EXTRUSION_WIDTH");

include <include/roundedcube.scad>
include <include/roundedCorner.scad>

$fn=$preview ? 20 : 100;

module keyboardDummy() {
    color("darkgrey")
    translate([0,0.11,PHONE_THICKNESS/2 + SCREEN_PROTECTOR_HEIGHT + KEYBOARD_PHONE_GAP_PERIMETERS*EXTRUSION_WIDTH])
        import("import/BBQ10KBD.stl", convexity=5);
}

module usbPortCutaway() {
    translate([-_USB_PORT_CUTAWAY_WIDTH/2, -_USB_PORT_CUTAWAY_LENGTH/2, -_USB_PORT_CUTAWAY_HEIGHT/2-USB_PORT_Y_OFFSET])
    roundedcube(size=[_USB_PORT_CUTAWAY_WIDTH, _USB_PORT_CUTAWAY_LENGTH, _USB_PORT_CUTAWAY_HEIGHT], center=false, radius=_USB_PORT_ROUNDING_RADIUS, apply_to=["y"]);
}

module speakerHole() {
    translate([-PHONE_SPEAKER_CUTAWAY_WIDTH/2+PHONE_SPEAKER_CUTAWAY_DISTANCE_FROM_CENTER, -_USB_PORT_CUTAWAY_LENGTH/2, -_USB_PORT_CUTAWAY_HEIGHT/2])
    roundedcube(size=[PHONE_SPEAKER_CUTAWAY_WIDTH, _USB_PORT_CUTAWAY_LENGTH, _USB_PORT_CUTAWAY_HEIGHT], center=false, radius=_USB_PORT_ROUNDING_RADIUS, apply_to=["y"]);
}

module phoneDummy() {
    union() {
        if (PHONE_DUMMY_FILE==""){
            color("purple")
            translate([0,-PHONE_KEYBOARD_OVERLAP,0])
            union() {
                translate([-PHONE_WIDTH/2, 0, -PHONE_THICKNESS/2])
                roundedcube(size=[PHONE_WIDTH, 50+CASE_SLEEVE_LENGTH, PHONE_THICKNESS], center=false, radius=PHONE_ROUNDING_RADIUS, apply_to=["all"]);
                usbPortCutaway();
                speakerHole();
            }
        } else {
            color("purple")
            translate([0,-PHONE_KEYBOARD_OVERLAP,0])
            scale([1.015,1.00,1.11]) //TOLLERANCE
            import(PHONE_DUMMY_FILE, convexity=5);
            if (FORCE_HOLE_CUTAWAYS) {
                usbPortCutaway();
                speakerHole();
            }
        }
        if (SCREEN_PROTECTOR_HEIGHT>0) {
            color("blue")
            translate([-PHONE_WIDTH/2+PHONE_ROUNDING_RADIUS/2, -PHONE_KEYBOARD_OVERLAP+.15, PHONE_THICKNESS/2])
            cube(size=[PHONE_WIDTH-PHONE_ROUNDING_RADIUS, PHONE_KEYBOARD_OVERLAP, SCREEN_PROTECTOR_HEIGHT], center=false);
        }
    }
}

module phoneRoundingBox() {
    translate([-CASE_WIDTH/2,_CASE_KEYBOARD_Y_OVERLAP-_CASE_BOTTOM_LENGTH,-PHONE_THICKNESS/2 - EXTRUSION_WIDTH*CASE_BOTTOM_PERIMETERS])
    hull() {
        difference() {
            intersection() {
                roundedcube(size=[CASE_WIDTH,_CASE_BOTTOM_LENGTH+100, CASE_THICKNESS + CASE_TOP_ROUNDING_OFFSET], center=false, radius=CASE_ROUNDING_RADIUS, apply_to=["all"]);
                //translate([0,0,-50])
                
                roundedcube(size=[CASE_WIDTH,_CASE_BOTTOM_LENGTH+150, CASE_THICKNESS + CASE_TOP_ROUNDING_OFFSET + 50], center=false, radius=CASE_BOTTOM_ROUNDING_RADIUS, apply_to=["z"]);
                
                roundedcube(size=[CASE_WIDTH,_CASE_BOTTOM_LENGTH+150, CASE_THICKNESS + CASE_TOP_ROUNDING_OFFSET + 50], center=false, radius=CASE_BOTTOM_ROUNDING_RADIUS, apply_to=["x"]);
            }
            color("blue")
            roundedCornerNegative([CASE_BOTTOM_ROUNDING_RADIUS,CASE_BOTTOM_ROUNDING_RADIUS+5,CASE_BOTTOM_ROUNDING_RADIUS]);
            
            translate([CASE_WIDTH,0,0])
            mirror([1,0,0])
            color("blue")
            roundedCornerNegative([CASE_BOTTOM_ROUNDING_RADIUS,CASE_BOTTOM_ROUNDING_RADIUS+5,CASE_BOTTOM_ROUNDING_RADIUS]);
        }
    }
}

module case() {
    translate([-CASE_WIDTH/2, _CASE_KEYBOARD_Y_OVERLAP-_CASE_BOTTOM_LENGTH-1, -PHONE_THICKNESS/2 - EXTRUSION_WIDTH*CASE_BOTTOM_PERIMETERS])
    cube(size=[CASE_WIDTH, _CASE_BOTTOM_LENGTH, CASE_THICKNESS], center=false);
}

module caseSleeve() {
    difference() {
        translate([-CASE_WIDTH/2, -1, -PHONE_THICKNESS/2-0.05 - EXTRUSION_WIDTH*CASE_BOTTOM_PERIMETERS])
        roundedcube(size=[CASE_WIDTH, CASE_SLEEVE_LENGTH+1, PHONE_THICKNESS+EXTRUSION_WIDTH*(CASE_BOTTOM_PERIMETERS+CASE_SLEEVE_TOP_PERIMETERS)-0.05], center=false, radius=CASE_SLEEVE_ROUNDING_RADIUS, apply_to=["y"]);
        
        translate([-PHONE_WIDTH/2+PHONE_ROUNDING_RADIUS/2, -1.5, -0.05])
        cube(size=[PHONE_WIDTH-PHONE_ROUNDING_RADIUS, CASE_SLEEVE_LENGTH+3, PHONE_THICKNESS+EXTRUSION_WIDTH*CASE_BOTTOM_PERIMETERS*2-0.05], center=false);
    }
}

module caseSleeveLink() {
    scaleFactor = 2*CASE_THICKNESS/(PHONE_THICKNESS+EXTRUSION_WIDTH*CASE_BOTTOM_PERIMETERS*2-0.05);
    translate([0, CASE_SLEEVE_LINK_LENGTH-1.5, 0])
    intersection() {
        /*{
            translate([-CASE_WIDTH/2, -51, -PHONE_THICKNESS/2-0.05 - EXTRUSION_WIDTH*CASE_BOTTOM_PERIMETERS])
            roundedcube(size=[CASE_WIDTH, CASE_SLEEVE_LENGTH+100, 100+PHONE_THICKNESS+EXTRUSION_WIDTH*CASE_BOTTOM_PERIMETERS*2-0.05], center=false, radius=CASE_SLEEVE_ROUNDING_RADIUS, apply_to=["y"]);
        }*/
        {
            rotate([-90,0,180])
            linear_extrude(height=CASE_SLEEVE_LINK_LENGTH,scale=[1,scaleFactor],slices=100) {
                projection()
                rotate([90,0,0])
                caseSleeve();
            }
        }
        case();
    }
}

module electronicsCutaway() {
    
    union() {
        color("pink")
        translate([-_ELECTRONICS_CUTAWAY_WIDTH/2, -PHONE_KEYBOARD_OVERLAP-_ELECTRONICS_BAY_TOPWALL_THICKNESS-_ELECTRONICS_CUTAWAY_LENGTH, -PHONE_THICKNESS/2+0.01+_ELECTRONICS_CUTAWAY_BACKWALL_EXTRAPERIMETERS*EXTRUSION_WIDTH])
        cube(size=[_ELECTRONICS_CUTAWAY_WIDTH, _ELECTRONICS_CUTAWAY_LENGTH, _ELECTRONICS_CUTAWAY_THICKNESS], center=false);
        
        /*color("red")
        translate([-_ELECTRONICS_CUTAWAY_WIDTH/2+0.005,
            -_ELECTRONICS_CUTAWAY_TOP_CLEARANCE-_ELECTRONICS_CUTAWAY_LENGTH,
            PHONE_THICKNESS*.5+EXTRUSION_WIDTH])
        cube(size=[_ELECTRONICS_CUTAWAY_WIDTH-0.01, _ELECTRONICS_CUTAWAY_LENGTH, (KEYBOARD_PHONE_GAP_PERIMETERS*2-1) * EXTRUSION_WIDTH], center=false);*/
    }
}

module usbAnvilCutaway() {
    color("teal")
    translate([0,-PHONE_KEYBOARD_OVERLAP-7,-USB_PORT_Y_OFFSET-2])
    cube([35,13,2], center=true);
}

module usbAnvil() {
    translate([0,-PHONE_KEYBOARD_OVERLAP,-USB_PORT_Y_OFFSET])
    import("import/USB_Anvil.stl");
}

module screwM3Countersunk(length) {
    union() {
        cylinder(length,d1=3,d2=3,center=true);
        translate([0,0,-10])
        cylinder(2,d1=6.5,d2=3,center=true);
        translate([0,0,-16])
        cylinder(10,d1=6.5,d2=6.5,center=true);
    }
}

module screwM2(length) {
    union() {
        translate([0, 0, -length])
        cylinder(length,d1=2,d2=2,center=false);
        translate([0,0,-length-10])
        cylinder(10,d1=3.5,d2=3.5,center=false);
    }
}

module usbScrewHoles() {
    union() {
        translate([-10,-PHONE_KEYBOARD_OVERLAP-4.25,5])
        screwM3Countersunk(20);
        translate([10,-PHONE_KEYBOARD_OVERLAP-4.25,5])
        screwM3Countersunk(20);
    }
}
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

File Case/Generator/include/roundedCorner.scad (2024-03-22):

module roundedCube2(dimensions, cornerDimensions) {
    cd = cornerDimensions;
    hull() {
        roundedCorner([cd[0],cd[1],cd[2]]);
        
        translate([dimensions[0],0,0])
        rotate([0,0,90])
        roundedCorner([cd[1],cd[3],cd[2]]);
        
        translate([0,0,dimensions[2]])
        rotate([0,90,0])
        roundedCorner([cd[4],cd[1],cd[0]]);
        
        translate([dimensions[0],0,dimensions[2]])
        rotate([0,90,90])
        roundedCorner([cd[4],cd[3],cd[1]]);
        
        translate([0,dimensions[1],0])
        rotate([90,0,0])
        roundedCorner([cd[0],cd[2],cd[5]]);
        
        translate([dimensions[0],dimensions[1],0])
        rotate([90,0,-90])
        roundedCorner([cd[5],cd[2],cd[3]]);
        
        translate([0,dimensions[1],dimensions[2]])
        rotate([90,90,0])
        roundedCorner([cd[4],cd[0],cd[5]]);
        
        translate([dimensions[0],dimensions[1],dimensions[2]])
        rotate([90,90,-90])
        roundedCorner([cd[4],cd[5],cd[3]]);
    }
}

module roundedCornerNegative(dimensions) {
    difference() {
        translate(dimensions/2)
        cube(size=dimensions, center=true);
        
        translate(dimensions)
        scale(dimensions)
        sphere(1);
    }
}

module roundedCorner(dimensions) {
    intersection() {
        translate(dimensions)
        scale(dimensions)
        sphere(1);
        
        translate(dimensions/2)
        cube(size=dimensions, center=true);
    }
}

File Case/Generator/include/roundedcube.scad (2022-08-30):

// Higher definition curves
$fs = 0.01;

function stringIn(string, list) = search([string],list)!=[[]];

module roundedcube(size = [1, 1, 1], center = false, radius = 0.5, apply_to = ["all"]) {
	// If single value, convert to [x, y, z] vector
	size = (size[0] == undef) ? [size, size, size] : size;

	translate_min = radius;
	translate_xmax = size[0] - radius;
	translate_ymax = size[1] - radius;
	translate_zmax = size[2] - radius;

	diameter = radius * 2;

	module build_point(type = "sphere", rotate = [0, 0, 0]) {
		if (type == "sphere") {
			sphere(r = radius);
		} else if (type == "cylinder") {
			rotate(a = rotate)
			cylinder(h = diameter, r = radius, center = true);
		}
	}

	obj_translate = (center == false) ?
		[0, 0, 0] : [
			-(size[0] / 2),
			-(size[1] / 2),
			-(size[2] / 2)
		];

	translate(v = obj_translate) {
		hull() {
			for (translate_x = [translate_min, translate_xmax]) {
				x_at = (translate_x == translate_min) ? "min" : "max";
				for (translate_y = [translate_min, translate_ymax]) {
					y_at = (translate_y == translate_min) ? "min" : "max";
					for (translate_z = [translate_min, translate_zmax]) {
						z_at = (translate_z == translate_min) ? "min" : "max";

						translate(v = [translate_x, translate_y, translate_z])
						if (
							(stringIn("all", apply_to)) ||
							(stringIn("xmin", apply_to) && x_at == "min") || (stringIn("xmax", apply_to) && x_at == "max") ||
							(stringIn("ymin", apply_to) && y_at == "min") || (stringIn("ymax", apply_to) && y_at == "max") ||
							(stringIn("zmin", apply_to) && z_at == "min") || (stringIn("zmax", apply_to) && z_at == "max")
						) {
							build_point("sphere");
						} else {
							rotate = 
								(stringIn("xmin", apply_to) || stringIn("xmax", apply_to) || stringIn("x", apply_to)) ? [0, 90, 0] : (
								(stringIn("ymin", apply_to) || stringIn("ymax", apply_to) || stringIn("y", apply_to)) ? [90, 90, 0] :
								[0, 0, 0]
							);
							build_point("cylinder", rotate);
						}
					}
				}
			}
		}
	}
}

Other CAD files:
Case/Generator/presets/Custom.scad
Case/Fairphone4/FairberryCase.blend
Case/Fairphone4/Flat-Case/flatCase.blend
Case/Generator/import/BBQ10KBD.blend
Case/Generator/presets/Fairphone4.scad
Case/Generator/presets/SamsungGalaxyA54.scad

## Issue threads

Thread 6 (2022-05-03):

Putting keyboard under the phone without overlap

dumblob, 2022-05-03:
I wonder whether you experimented with putting the keyboard under the phone (like BlackBerry KEY 1, BlackBerry KEY 2, Unihertz Titan Slim)?

If not, would you have any suggestions, observations, or links?

Thanks!

Dakkaron, 2022-05-03:
I actually tried that before settling on this design, where the keyboard overlaps the chin of the phone.
The problem is, that that causes further imbalance and makes the phone even longer.

It might work with a smaller phone but the FP4 is tall as it is. Maybe, the FP4 isn't the best phone for this purpose, but it's the one I have.

I first had the solution on my temporary Honor 9 Lite, and there the balance and size was better.

I was thinking about remaking the case in OpenSCAD so that anyone can generate a version fitting for their own phone. Shouldn't be too hard.

Another problem, though, would be that the USB connector probably would be in the way of the keyboard. So it would probably have to be thicker anyways.

dumblob, 2022-05-03:
>The problem is, that that causes further imbalance and makes the phone even longer.

Regarding imbalance it's from my experience more about getting used to rather than a serious issue (on my BlackBerry I've learned to use side bezels by my thumbs as stabilizer - it could be even improved if the case is designed with a few millimeters more thickness at the "balance point" on both sides).

But the length, that's already a problem, no doubts.

>I was thinking about remaking the case in OpenSCAD so that anyone can generate a version fitting for their own phone. Shouldn't be too hard.

Maybe adding a "Sheet" in FreeCAD with some variables (dimensions, radiuses of long top edges, short top edges, long bottom edges, short bottom edges) could be enough (and simpler for beginners)?

>Another problem, though, would be that the USB connector probably would be in the way of the keyboard. So it would probably have to be thicker anyways.

1-2 mm is fine. 3 or more mm looks gross though :wink:.

Or maybe a simple custom tiny narrow PCB with the USB connector soldered on it could be an alternative to explore. IDK

Dakkaron, 2022-05-04:
> Regarding imbalance it's from my experience more about getting used to rather than a serious issue (on my BlackBerry I've learned to use side bezels by my thumbs as stabilizer - it could be even improved if the case is designed with a few millimeters more thickness at the "balance point" on both sides).

Currently, I hook my middle fingers into the back of the keyboard. This helps with the balance as well.

> But the length, that's already a problem, no doubts.

Another problem with the length is durability. The keyboard is a weak point in the structure. If it's too long and you pocket the phone with the keyboard attached, it becomes easier to accidentally break, if it's longer.

> Maybe adding a "Sheet" in FreeCAD with some variables (dimensions, radiuses of long top edges, short top edges, long bottom edges, short bottom edges) could be enough (and simpler for beginners)?

Thingiverse has this Customizer feature, where you import OpenSCAD code and it generates a nice GUI form where the users can input their values and it generates a fitting part in STL format.

> 1-2 mm is fine. 3 or more mm looks gross though 😉.

I understand what you mean^^

Currently, the thickness is mostly limited by the keyboard's hooks at the front. I guess, I could remove the hooks to shave off some thickness. But then the limiting factor becomes the PCB and the parts on it. If I find someone to make a custom PCB (or somehow manage to learn KiCAD^^), it might be possible to shave off some more thickness. Another problem is the keyboard's flex PCB connector. It needs to be bent twice to fit under the keyboard, and I don't want the bend radius to be too small, cause that might break the flex PCB.

I'd actually really like to use the Keyone-Keyboard, because that would solve some issues (it's a bit shorter and the connector is at a much better position), but there is no information at all about it, I don't even know the name of the connector...

dumblob, 2022-05-04:
> Another problem with the length is durability. The keyboard is a weak point in the structure. If it's too long and you pocket the phone with the keyboard attached, it becomes easier to accidentally break, if it's longer.

Actually durability can be solved quite easily as far as my experience goes - materials, thickness, making the keyboard into a full-covering cover, etc.

> > Maybe adding a "Sheet" in FreeCAD with some variables (dimensions, radiuses of long top edges, short top edges, long bottom edges, short bottom edges) could be enough (and simpler for beginners)?
>
> Thingiverse has this Customizer feature, where you import OpenSCAD code and it generates a nice GUI form where the users can input their values and it generates a fitting part in STL format.

Oh, didn't know about this feature. Is it available also for non-registered users?

If not, then there is not that much of a difference between the work needed in both approaches :wink: (it'll be anyway dominated by looking for a caliper and measuring all the dimensions etc.).

> Currently, the thickness is mostly limited by the keyboard's hooks at the front. I guess, I could remove the hooks to shave off some thickness.

I didn't even notice you didn't remove them :smile: (when I was looking at aliexpress photos of the keyboard the first thought was to remove them and other surrounding "overhangs" etc. at all cost :wink:).

>But then the limiting factor becomes the PCB and the parts on it. If I find someone to make a custom PCB (or somehow manage to learn KiCAD^^), it might be possible to shave off some more thickness.

Definitely. The PCB can be actually very small. I know one PCB ninja - but he will have time for it first in couple of months probably. I'll ask him. But in no way I want to discourage you - learning KiCAD basics is super useful!

>Another problem is the keyboard's flex PCB connector. It needs to be bent twice to fit under the keyboard, and I don't want the bend radius to be too small, cause that might break the flex PCB.

This one should be really easy to solve - just leave groovy holes in the custom PCB (and/or other plates/material layers) at the places where the folds shall happen and they'll form a nice round bend with >1 mm radius. Or at least that's how I did it in the past.

> I'd actually really like to use the Keyone-Keyboard, because that would solve some issues (it's a bit shorter and the connector is at a much better position), but there is no information at all about it, I don't even know the name of the connector...

Yep. OTOH maybe the [fully automated sniffer](https://www.instructables.com/How-to-Make-a-USB-Laptop-Keyboard-Controller/ ) could do the work for us?

Dakkaron, 2022-05-04:
>Actually durability can be solved quite easily as far as my experience goes - materials, thickness, making the keyboard into a full-covering cover, etc.

Sure, but on the one hand, using metal will make the thing pretty heavy. On the other hand, anything except 3D printed parts is hard to get and/or expensive.

>I didn't even notice you didn't remove them 😄 (when I was looking at aliexpress photos of the keyboard the first thought was to remove them and other surrounding "overhangs" etc. at all cost 😉).

The keyboard itself is 3mm thick. The hooks are another 3mm. I didn't remove the hooks, because I fit the PCB in there anyway. The PCB + adhesive + components and leads are almost 3mm in height, so the hooks don't add much.

The whole assembly currently adds 8mm on top of the phone, and 1mm at the bottom. Since the PCB assembly is now a little flatter than it used to be, I could probably shave off 1-2mm at the top.

Looking at my fat Fairphone 4, it has about 3mm above the USB C port. So with a bit of tinkering, it could be possible to fit the keyboard over the USB C connector and be almost flush with the phone's  screen.

> Definitely. The PCB can be actually very small. I know one PCB ninja - but he will have time for it first in couple of months probably. I'll ask him. But in no way I want to discourage you - learning KiCAD basics is super useful!

That would be a lot of help! I've been trying to learn KiCAD for a while now. I can do footprints and schematics, but I got lost at actually creating the PCB.

I've asked a few guys on fiverr, but didn't get any replies yet.

> Yep. OTOH maybe the [fully automated sniffer](https://www.instructables.com/How-to-Make-a-USB-Laptop-Keyboard-Controller/) could do the work for us?
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
dumblob, 2022-05-05:
> I did a bit of thinking. If we allow the keyboard to raise up to 2mm above the phone, we can easily fit even a wired USB C port under the keyboard. Actually, it might work as is on my phone. I'll try to print something if I find the time.

Any pictures of printed stuff or just 3D models would be appreciated to see how it would look like in practice :wink:.

> I'd like to have the plug to be connected using wires and then attach the plug PCB to the case, so that it's plugged in by attaching the case, but without putting strain onto solder leads. That way, it would also be much easier to allow for Micro USB ports as well.

That's also an option - but much more work and hassle IMHO. But maybe it's not that bad. IDK

> Is this durable? Flexing a non-flex PCB doesn't sound safe. But I don't have any experience with that.

Yes, it is really durable. It's being used in professional products of known brands (incl. e.g. Siemens AG). So I wouldn't be afraid of it.

> Btw, I measured the discharge rate on my phone, and it discharged by around 60mAh, which is probably due to DCDC power conversion that I didn't account for. Also, I guess, the USB stack on the phone also consumes some power. The resolution of my phone's discharge measurement is 10mAh, so the 60mAh is a quite rough guess.

Yes, power conversion is another source of huge leakage. Thanks for noticing!

> > Instead of hardcore-gaming you could simply make a recording like Dan Luu in https://danluu.com/keyboard-latency/ . And one more link to consider wink https://bdickason.com/posts/speed-is-the-killer-feature/ .
>
> I don't have a logic analyser, so that's hard for me to measure. But the latency is not so slow that I would notice at all.

I mean, Dan didn't use any logic analyzer but measured end-to-end latency with a camera (60fps is a pretty standard nowadays; with sport cameras you get (much) more).

> Maybe I could add some key combination or a switch that puts the keyboard to sleep mode or something.

I for myself wouldn't use such feature either - it's no different than pressing a button and waiting 2s for it to react. It's also a similar mental model to unplugging the whole keyboard from the phone. So really of no use for my workflow. But maybe for yours it'd be a different story.

> Reducing the clock frequency from 16MHz to 1MHz will reduce the power consumption by ~15mAh. That would be quite a bit.

:+1:

>I don't use multiplexers or something, only direct GPIO.

:+1:

Dakkaron, 2022-05-06:
Since it's more of a discussion than a straight issue, I'd suggest, we continue our discussion in the discussions section.

Here is the discussion regarding the flat keyboard: https://github.com/Dakkaron/Fairberry/discussions/8

Here is one regarding the power consumption: https://github.com/Dakkaron/Fairberry/discussions/9

And this one is regarding the connector: https://github.com/Dakkaron/Fairberry/discussions/10

Did I miss anything?

I'll close this issue, since the discussion feature is more useful for discussions^^

dumblob, 2022-05-07:
Thanks! I'll take a look at the separate threads later - now I'm too busy.

Closed 2022-05-06.

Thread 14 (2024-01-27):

Keyboard not working on Android, but on the PC

aligator, 2024-01-27:
Hi, thanks for the great project!

I think I soldered everything correctly as it works flawlessly when connected to the PC. So the tiny connector should be ok.
But on the phone it just doesn't get recognized by android. The android settings say that no external keyboard is connected.

Do you have any idea how I could troubleshoot this problem?
I use Android 13 on a Fairphone 4 and also tried a Shift phone with Android 13... On both it doesn't work.

aligator, 2024-01-27:
I think my USBC breakout board is somehow bad. It doesn't deliver 5V. Maybe it doesn't implement the USB standard correctly....
If I use an usb hub between the phone and the keyboard it works.

Dakkaron, 2024-01-27:
That could very well be true. Did you check that your USB C breakout boards are USB OTG?

Since it's bidirectional, by default USBC doesn't output power. It needs to be configured so that the phone knows that it needs to power the USB connector.

aligator, 2024-01-30:
If anyone else has this problem:

I just soldered a resistor ~5,1k between the CC pin and Ground and now it works.
Not easy though with these little pins.
Basically i just added Flux and no new solder to it.

Make sure it does not touch the pins beside the CC pin.

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

After that plug it in and check if it gives you now 5V.

Note that if it is done on one side only , the connector works only in one direction.
However that is ok here because i won't rotate the keyboard.

@Dakkaron maybe you add a note about this to the instructions?

Dakkaron, 2024-01-30:
Congrats to your working keyboard!

Adding it to the documentation (maybe in a troubleshooting section) makes a lot of sense.

Closed 2024-01-30.

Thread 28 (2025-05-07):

JLCPCB alternative

metametapod, 2025-05-07:
Hi, thank you for putting together this project. Do you have any recommended alternatives to JLCPCB to avoid [US tariffs](https://jlcpcb.com/help/article/us-tariff-policy-faq)?

Disclaimer: new to electronics

Dakkaron, 2025-05-23:
Sorry, I'm not from the US, so I don't have any experience with that. Oshpark is the only one that comes to mind, but afaik they only make PCBs and don't do assembly. So you'd have to source and solder all the components manually, which for a beginner isn't trivial.

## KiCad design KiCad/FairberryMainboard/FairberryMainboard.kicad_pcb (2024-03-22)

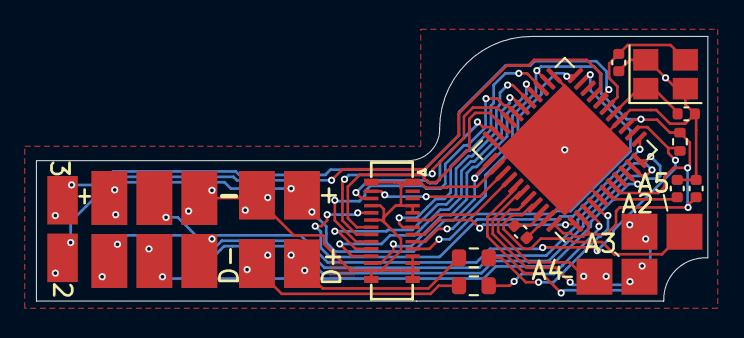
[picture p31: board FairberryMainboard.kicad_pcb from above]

Board: 2 copper layers, 37.3 x 14.7 mm, 13 parts (0 on the bottom side), 28 nets.

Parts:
C1: 1uF; C_0402_1005Metric
C2, C3: 0.1uF; C_0402_1005Metric
C4, C5: 22pF; C_0402_1005Metric
J1: USB_Header; TestPoint_Pad_2x2_2.0x3.0mm
J2: Conn_02x03_Odd_Even; TestPoint_Pad_2x3_2.0x3.0mm
R1: 10K; R_0402_1005Metric
R2, R3: 22; R_0603_1608Metric
U1: ATmega32U4-MU; QFN-44-1EP_7x7mm_P0.5mm_EP5.2x5.2mm
U2: BBQ10KBD; BM14B(0.8)-24DS-0.4V(53)
Y1: Crystal_GND24; Crystal_SMD_SeikoEpson_FA238-4Pin_3.2x2.5mm

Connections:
/USB_Plug_D+: J1.4, R2.2
/USB_Plug_D-: J1.3, R3.2
/USB_UC_D+: R2.1, U1.4 (D+)
/USB_UC_D-: R3.1, U1.3 (D-)
GND: C1.2, C2.2, C3.2, C4.2, C5.2, J1.1, J2.6, U1.5 (UGND), U1.15 (GND), U1.23 (GND), U1.33 (~HWB/PE2), U1.35 (GND), U1.43 (GND), U1.45 (GND), U2.1 (GND), U2.4 (AGND), U2.5 (GND), U2.11 (GND), U2.12 (GND), U2.13 (GND), U2.14 (GND), U2.15 (GND), U2.16 (GND), U2.23 (LEDK_2_3), U2.25 (LEDK_1_4), U2.28 (GND), Y1.2, Y1.4
unnamed: C1.1, U1.6 (UCAP)
unnamed: C3.1, U1.42 (AREF)
unnamed: C4.1, U1.16 (XTAL2), Y1.1
unnamed: C5.1, U1.17 (XTAL1), Y1.3
unnamed: J2.1, U1.11 (PB3)
unnamed: J2.3, U1.9 (PB1)
unnamed: J2.4, U1.10 (PB2)
unnamed: J2.5, R1.2, U1.13 (~RESET)
unnamed: U1.1 (PE6), U2.8 (ROW2)
unnamed: U1.12 (PB7), U2.24 (LEDA_3_4)
unnamed: U1.21 (PD3), U2.10 (COL3)
unnamed: U1.22 (PD5), U2.9 (COL2)
unnamed: U1.25 (PD4), U2.7 (COL1)
unnamed: U1.26 (PD6), U2.17 (COL4)
unnamed: U1.27 (PD7), U2.19 (COL5)
unnamed: U1.28 (PB4), U2.18 (ROW3)
unnamed: U1.29 (PB5), U2.20 (ROW4)
unnamed: U1.30 (PB6), U2.21 (ROW5)
unnamed: U1.31 (PC6), U2.22 (ROW6)
unnamed: U1.32 (PC7), U2.26 (LEDA_1_2)
unnamed: U1.36 (PF7), U2.27 (ROW7)
unnamed: U1.37 (PF6), U2.6 (ROW1)
VCC: C2.1, J1.2, J2.2, R1.1, U1.2 (UVCC), U1.7 (VBUS), U1.14 (VCC), U1.24 (AVCC), U1.34 (VCC), U1.44 (AVCC)

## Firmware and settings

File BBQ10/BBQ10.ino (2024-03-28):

// Fairberry Keyboard Firmware © 2024 by Dakkaron is licensed under Attribution-NonCommercial-ShareAlike 4.0 International.
// To view a copy of this license, visit http://creativecommons.org/licenses/by-nc-sa/4.0/
// Version 3

#define FAIRBERRY_V0_3_0 3
#define FAIRBERRY_V0_2_0 2
#define FAIRBERRY_V0_1_1 1
#define ARDUINO 10
#define BEETLE 1101
#define ESP32 1102


#define CHIP_ATMEGA32U4 1
#define CHIP_ESP32 2

#include "configuration.h"
#include "constants.h"
#include "keymaps.h"
#include "boards.h"


bool keys[colCount][rowCount];
bool lastValue[colCount][rowCount];
bool changedValue[colCount][rowCount];
byte debounceMs[colCount][rowCount];
unsigned long lastDebounceMs;


int keyboardLightSteps = 20;
int keyboardLight1 = DEFAULT_KEYBOARD_BRIGHTNESS;
int keyboardLight2 = DEFAULT_KEYBOARD_BRIGHTNESS;
volatile unsigned long idleTimeout = millis() + IDLE_TIMEOUT;
volatile unsigned long backlightTimeout = millis() + BACKLIGHT_TIMEOUT;
volatile unsigned long blinkTimeout = millis() + BLINK_TIMEOUT;
volatile bool isClockedDown = false;
bool blinkState = true;
bool idleWakeup = false;
bool firstSleep = true;
bool connectionNeedsReinit1 = false;
volatile unsigned long connectionNeedsReinit2 = false;

#define USB_ADDRESS_EXISTS (_BV(ADDEN)==0x80 && UDINT > 0)
bool usbGotDisconnected = false;

bool anyKeyReleased = false;

byte stickySym = STICKY_STATUS_OPEN;
byte stickyLsh = STICKY_STATUS_OPEN;
byte stickyRsh = STICKY_STATUS_OPEN;
byte stickyCtrl = STICKY_STATUS_OPEN;
byte stickyAlt = STICKY_STATUS_OPEN;
bool cursorMode = false;

#define KEYBOARD_CONNECTION_READY keyboardConnectionReadyTimeout < millis()
#define ACTIVATE_KEYBOARD_CONNECTION_BUFFER() keyboardConnectionReadyTimeout = millis() + 500;
unsigned long keyboardConnectionReadyTimeout=0;

void(* resetFunc) (void) = 0;

void setup() {
    #ifdef LED0_PIN
      pinMode(LED0_PIN, OUTPUT);
    #endif
    #ifdef LED1_PIN
      pinMode(LED1_PIN, OUTPUT);
    #endif
    #if BOARD_TYPE == ESP32
      KEYBOARD_BEGIN(KeyboardLayout_en_US);
      
      esp_bt_sleep_enable();
      
      esp_pm_config_esp32_t pm_config;
      pm_config.max_freq_mhz = 80;
      pm_config.min_freq_mhz = 80;
      pm_config.light_sleep_enable = true;
      esp_pm_configure(&pm_config);

      esp_wifi_set_mode(WIFI_MODE_NULL);
    #endif
    for(int i=0; i<rowCount; i++) {
        #ifdef SERIAL_DEBUG_LOG
          Serial.print(rows[i]); Serial.println(" as input");
        #endif
        pinMode(rows[i], INPUT);
    }
 
    for (int i=0; i<colCount; i++) {
        #ifdef SERIAL_DEBUG_LOG
          Serial.print(cols[i]); Serial.println(" as input-pullup");
        #endif
        #ifdef FASTCOLS
          FASTCOLS_PINCONFIG = FASTCOLS_PINCONFIG & !(1 << cols[i]);
          FASTCOLS_PORT = FASTCOLS_PORT & !(1 << cols[i]);
        #else
          pinMode(cols[i], INPUT);
        #endif
    }

    // set pins for the keyboard backlight
    #ifdef KEYBOARD_LIGHT_PIN_1
      pinMode(KEYBOARD_LIGHT_PIN_1, OUTPUT);
    #endif
    #ifdef KEYBOARD_LIGHT_PIN_2
      pinMode(KEYBOARD_LIGHT_PIN_2, OUTPUT);
    #endif

    setKeyboardBacklight(keyboardLight1, keyboardLight2, true);
    lastDebounceMs = millis();

    while (USBDevice.isSuspended()) {}
    USBCON |= (1 << USBE);
    USBDevice.attach();
}

void updateStickyKeyStates() {
  if (keyPressed(K_SYM) && !keyActive(K_MIC)) { // SYM(0,2) (inactive while CTRL(0,6) is held, because of brightness down)
    byte tmp = stickySym;
    resetStickyKeys();
    stickySym = tmp + 1;
  }
  if (keyPressed(K_LSH)) { // LSH(1,6)
    byte tmp = stickyLsh;
    resetStickyKeys();
    stickyLsh = tmp + 1;
  }
  if (keyPressed(K_RSH) && !keyActive(K_MIC)) { // RSH(2,3) (inactive while CTRL(0,6) is held, because of brightness down)
    byte tmp = stickyRsh;
    resetStickyKeys();
    stickyRsh = tmp + 1;
  }
  if (stickySym==STICKY_STATUS_OPEN && keyPressed(K_MIC)) { // CTRL(0,6)
    byte tmp = stickyCtrl;
    resetStickyKeys();
    stickyCtrl = tmp + 1;
  }
  if (stickySym==STICKY_STATUS_OPEN && keyPressed(K_ALT)) { // ALT(0,4)
    byte tmp = stickyAlt;
    resetStickyKeys();
    stickyAlt = tmp + 1;
  }
}

void rolloverStickyKeyStates() {
  #ifndef STICKY_SYM
    if (stickySym == STICKY_STATUS_STICKY) {
      stickySym++;
    }
  #endif
  #ifndef STICKY_LSH
    if (stickyLsh == STICKY_STATUS_STICKY) {
      stickyLsh++;
    }
  #endif
  #ifndef STICKY_RSH
    if (stickyRsh == STICKY_STATUS_STICKY) {
      stickyRsh++;
    }
  #endif
  #ifndef STICKY_CTRL
    if (stickyCtrl == STICKY_STATUS_STICKY) {
      stickyCtrl++;
    }
  #endif
  #ifndef STICKY_ALT
    if (stickyAlt == STICKY_STATUS_STICKY) {
      stickyAlt++;
    }
  #endif

  #ifndef DOUBLETAP_LOCK_SYM
    if (stickySym == STICKY_STATUS_LOCKED) {
      stickySym++;
    }
  #endif
  #ifndef DOUBLETAP_LOCK_LSH
    if (stickyLsh == STICKY_STATUS_LOCKED) {
      stickyLsh++;
    }
  #endif
  #ifndef DOUBLETAP_LOCK_RSH
    if (stickyRsh == STICKY_STATUS_LOCKED) {
      stickyRsh++;
    }
  #endif
  #ifndef DOUBLETAP_LOCK_CTRL
    if (stickyCtrl == STICKY_STATUS_LOCKED) {
      stickyCtrl++;
    }
  #endif
  #ifndef DOUBLETAP_LOCK_ALT
    if (stickyAlt == STICKY_STATUS_LOCKED) {
      stickyAlt++;
    }
  #endif

  if (stickySym > STICKY_STATUS_LOCKED) {
    stickySym = STICKY_STATUS_OPEN;
  }
  if (stickyLsh > STICKY_STATUS_LOCKED) {
    stickyLsh = STICKY_STATUS_OPEN;
  }
  if (stickyRsh > STICKY_STATUS_LOCKED) {
    stickyRsh = STICKY_STATUS_OPEN;
  }
  if (stickyCtrl > STICKY_STATUS_LOCKED) {
    stickyCtrl = STICKY_STATUS_OPEN;
  }
  if (stickyAlt > STICKY_STATUS_LOCKED) {
    stickyAlt = STICKY_STATUS_OPEN;
  }
}

void wakeEverythingUp() {
  changeKeyboardBacklight(0, 0, true);
  idleTimeout = millis() + IDLE_TIMEOUT;
  backlightTimeout = millis() + BACKLIGHT_TIMEOUT;
  #ifdef POWERSAVE_ARDUINO_CLOCKDOWN
    if (isClockedDown) {
      CLKPR = 0b10000000;
      CLKPR = ARDUINO_CLOCKDOWN_RESET_VALUE;
      CLKPR = ARDUINO_CLOCKDOWN_RESET_VALUE;
      CLKPR = ARDUINO_CLOCKDOWN_RESET_VALUE;
      isClockedDown = false;
    }
  #endif
  #ifdef POWERSAVE_ARDUINO_POWERDOWN
    if (connectionNeedsReinit1) {
      digitalWrite(LED1_PIN, 1);
      connectionNeedsReinit1 = false;
      connectionNeedsReinit2 = millis()+200;
      USBDevice.attach();
      ACTIVATE_KEYBOARD_CONNECTION_BUFFER();
    } else if (connectionNeedsReinit2!=0 && connectionNeedsReinit2<millis()) {
      KEYBOARD_BEGIN(KeyboardLayout_en_US);
      #ifdef SERIAL_DEBUG_LOG
        Serial.print(millis());
        Serial.println(": Activated connection buffer");
      #endif
      digitalWrite(LED1_PIN, 0);
      connectionNeedsReinit2 = 0;
    }
  #endif
  #ifdef POWERSAVE_ESP32_LIGHT_SLEEP
    if (connectionNeedsReinit1) {
      pinMode(RESET_PIN, OUTPUT);
      digitalWrite(RESET_PIN, LOW);
      
      /*connectionNeedsReinit1 = false;
      btStart();
      KEYBOARD_BEGIN(KeyboardLayout_en_US);*/
    }
  #endif
}

boolean anyKeyPressed = false;
/**
 * Returns whether any key was changed (true == at least one key changed state)
 */
boolean readMatrix(byte debouceMsSinceLast) {
  int delayTime = 0;
  anyKeyReleased = false;
  boolean anyKeyChanged = false;
  boolean anyKeyPressed = true;
  #ifdef FASTCHECK
    #ifdef FASTCOLCHECK_D
      DDRD |= FASTCOLCHECK_D;
      PORTD &= ~FASTCOLCHECK_D;
    #endif
    #ifdef FASTROWCHECK_B
      DDRB &= ~FASTROWCHECK_B;
      PORTB |= FASTROWCHECK_B;
    #endif
    #ifdef FASTROWCHECK_C
      DDRC &= ~FASTROWCHECK_C;
      PORTC |= FASTROWCHECK_C;
    #endif
    #ifdef FASTROWCHECK_D
      DDRD &= ~FASTROWCHECK_D;
      PORTD |= FASTROWCHECK_D;
    #endif
    #ifdef FASTROWCHECK_E
      DDRE &= ~FASTROWCHECK_E;
      PORTE |= FASTROWCHECK_E;
    #endif
    #ifdef FASTROWCHECK_F
      DDRF &= ~FASTROWCHECK_F;
      PORTF |= FASTROWCHECK_F;
    #endif
    delayMicroseconds(10);
    anyKeyPressed = false;
    #ifdef FASTROWCHECK_B
      anyKeyPressed |= ((~PINB) & FASTROWCHECK_B);
      PORTB &= ~FASTROWCHECK_B;
    #endif
    #ifdef FASTROWCHECK_C
      anyKeyPressed |= ((~PINC) & FASTROWCHECK_C);
      PORTC &= ~FASTROWCHECK_C;
    #endif
    #ifdef FASTROWCHECK_D
      anyKeyPressed |= ((~PIND) & FASTROWCHECK_D);
      PORTD &= ~FASTROWCHECK_D;
    #endif
    #ifdef FASTROWCHECK_E
      anyKeyPressed |= ((~PINE) & FASTROWCHECK_E);
      PORTE &= ~FASTROWCHECK_E;
    #endif
    #ifdef FASTROWCHECK_F
      anyKeyPressed |= ((~PINF) & FASTROWCHECK_F);
      PORTF &= ~FASTROWCHECK_F;
    #endif
    #ifdef FASTCOLCHECK_D
      DDRD &= ~FASTCOLCHECK_D;
    #endif
  #endif

  
  for (int rowIndex=0; rowIndex < rowCount; rowIndex++) {
    // iterate the columns
    byte curRow = rows[rowIndex];
    if (anyKeyPressed) {
      pinMode(curRow, INPUT_PULLUP);
    }
    
    for (int colIndex=0; colIndex < colCount; colIndex++) {
      // col: set to output to low
      byte curCol = cols[colIndex];
      if (anyKeyPressed) {
        #ifdef FASTCOLS
          FASTCOLS_PINCONFIG = FASTCOLS_PINCONFIG | (1 << curCol);
          FASTCOLS_PORT = FASTCOLS_PORT & !(1 << curCol);
        #else
          pinMode(curCol, OUTPUT);
          digitalWrite(curCol, LOW);
        #endif
      }

      if (debounceMs[colIndex][rowIndex]>0) { // If debouncing is still active for this key, ignore all input
        if (debounceMs[colIndex][rowIndex] >= debouceMsSinceLast) {
          debounceMs[colIndex][rowIndex] -= debouceMsSinceLast;
        } else {
          debounceMs[colIndex][rowIndex] = 0;
        }
        changedValue[colIndex][rowIndex] = false;
      } else { // If debouncing is not active, process the key press
        bool buttonPressed = (anyKeyPressed) && (digitalRead(curRow) == LOW);
        
        keys[colIndex][rowIndex] = buttonPressed;
        if ((lastValue[colIndex][rowIndex] != buttonPressed)) {
          changedValue[colIndex][rowIndex] = true;
          debounceMs[colIndex][rowIndex] = DEBOUNCE_MS;
          anyKeyReleased = anyKeyReleased | buttonPressed;
          anyKeyChanged = true;
        } else {
          changedValue[colIndex][rowIndex] = false;
        }
  
        lastValue[colIndex][rowIndex] = buttonPressed;
      }

      if (anyKeyPressed) {
        #ifdef FASTCOLS
          FASTCOLS_PINCONFIG = FASTCOLS_PINCONFIG & !(1 << curCol);
          FASTCOLS_PORT = FASTCOLS_PORT & !(1 << curCol);
        #else
          pinMode(curCol, INPUT);
        #endif
      }
    }
    if (anyKeyPressed) {
      pinMode(curRow, INPUT);
    }
  }

  #ifdef FASTROWCHECK_B
    DDRB &= ~FASTROWCHECK_B;
    PORTB |= FASTROWCHECK_B;
  #endif
  #ifdef FASTROWCHECK_C
    DDRC &= ~FASTROWCHECK_C;
    PORTC |= FASTROWCHECK_C;
  #endif
  #ifdef FASTROWCHECK_D
    DDRD &= ~FASTROWCHECK_D;
    PORTD |= FASTROWCHECK_D;
  #endif
  #ifdef FASTROWCHECK_E
    DDRE &= ~FASTROWCHECK_E;
    PORTE |= FASTROWCHECK_E;
  #endif
  #ifdef FASTROWCHECK_F
    DDRF &= ~FASTROWCHECK_F;
    PORTF |= FASTROWCHECK_F;
  #endif
  #ifdef FASTCOLCHECK_D
    DDRD &= ~FASTCOLCHECK_D;
    PORTD |= FASTCOLCHECK_D;
  #endif

  updateStickyKeyStates();
  rolloverStickyKeyStates();

  if (anyKeyReleased) {
    wakeEverythingUp();
  }
  return anyKeyChanged;
}

bool keyPressed(int colIndex, int rowIndex) {
  return changedValue[colIndex][rowIndex] && keys[colIndex][rowIndex] == true;
}

bool keyReleased(int colIndex, int rowIndex) {
  return changedValue[colIndex][rowIndex] && keys[colIndex][rowIndex] == false;
}

bool keyChanged(int colIndex, int rowIndex) {
  return changedValue[colIndex][rowIndex];
}

bool keyActive(int colIndex, int rowIndex) {
  return keys[colIndex][rowIndex] == true;
}

bool isPrintableKey(int colIndex, int rowIndex) {
  return keyboard_symbol[colIndex][rowIndex] != NULL || keyboard[colIndex][rowIndex] != NULL;
}

void changeKeyboardBacklight(int change1, int change2, bool on) {
  setKeyboardBacklight(keyboardLight1 + change1, keyboardLight2 + change2, on);
}

void setKeyboardBacklight(int pwmValue1, int pwmValue2, bool on) {
  if (pwmValue1 > 255) {
    pwmValue1 = 255;
  }
  if (pwmValue1 < 0) {
    pwmValue1 = 0;
  }
  if (pwmValue2 > 255) {
    pwmValue2 = 255;
  }
  if (pwmValue2 < 0) {
    pwmValue2 = 0;
  }
  keyboardLight1 = pwmValue1;
  keyboardLight2 = pwmValue2;
  if (on) {
    #ifdef KEYBOARD_LIGHT_PIN_1
      analogWrite(KEYBOARD_LIGHT_PIN_1, keyboardLight1);
    #endif
    #ifdef KEYBOARD_LIGHT_PIN_2
      analogWrite(KEYBOARD_LIGHT_PIN_2, keyboardLight2);
    #endif
  } else {
    #ifdef KEYBOARD_LIGHT_PIN_1
      analogWrite(KEYBOARD_LIGHT_PIN_1, 0);
    #endif
    #ifdef KEYBOARD_LIGHT_PIN_2
      analogWrite(KEYBOARD_LIGHT_PIN_2, 0);
    #endif
  }
}

void unstickKeys() {
  if (anyKeyReleased) {
    stickySym = (stickySym==STICKY_STATUS_STICKY) ? keyPressed(K_SYM) : stickySym;
    stickyLsh = (stickyLsh==STICKY_STATUS_STICKY) ? keyPressed(K_LSH) : stickyLsh;
    stickyRsh = (stickyRsh==STICKY_STATUS_STICKY) ? keyPressed(K_RSH) : stickyRsh;
    stickyCtrl= (stickyCtrl==STICKY_STATUS_STICKY)? keyPressed(K_MIC) : stickyCtrl;
    stickyAlt = (stickyAlt==STICKY_STATUS_STICKY) ? keyPressed(K_ALT) : stickyAlt;
  }
}

void resetStickyKeys() {
  stickySym = STICKY_STATUS_OPEN;
  stickyLsh = STICKY_STATUS_OPEN;
  stickyRsh = STICKY_STATUS_OPEN;
  stickyCtrl= STICKY_STATUS_OPEN;
  stickyAlt = STICKY_STATUS_OPEN;
}

char keyPressBuffer[32]; //0=End of presses in buffer 
uint32_t keyPressBufferType; //1=press, 0=release

void flushKeyboardBuffer() {
  #ifdef SERIAL_DEBUG_LOG
    Serial.print(millis());
    Serial.println(": Flushing buffer");
  #endif
  for (uint8_t i=0;i<32;i++) {
    if (keyPressBuffer[i]!=0) {
      bool pressed = !!(keyPressBufferType & (1ull<<i));
      if (pressed) {
        KEYBOARD_PRESS(keyPressBuffer[i]);
        #ifdef SERIAL_DEBUG_LOG
          Serial.print("Pressed slot ");
          Serial.print(i);
          Serial.print("/");
          Serial.println(keyPressBuffer[i]);
        #endif
        bool foundRelease = false;
        for (uint8_t j=i+1;j<32;j++) {
          if (keyPressBuffer[j]==keyPressBuffer[i] && !(keyPressBufferType & (1ull<<i))) {
            foundRelease = true;
          }
        }
        if (!foundRelease) {
          #ifdef SERIAL_DEBUG_LOG
            Serial.println("Sending missing release");
          #endif
          KEYBOARD_RELEASE(keyPressBuffer[i]);
        }
      } else {
        KEYBOARD_RELEASE(keyPressBuffer[i]);
        #ifdef SERIAL_DEBUG_LOG
          Serial.print("Released slot ");
          Serial.print(i);
          Serial.print("/");
          Serial.println(keyPressBuffer[i]);
        #endif
        delay(30);
      }
      keyPressBuffer[i]=0;
    }
  }
}

void keyboardEventBuffered(char key, bool pressed) {
  #ifdef SERIAL_DEBUG_LOG
    Serial.print("Key event buffered: ");
    Serial.print(key);
    Serial.print("/");
    Serial.print((uint8_t)key);
    Serial.print("/");
    Serial.print(pressed);
    Serial.print("/");
    Serial.println(KEYBOARD_CONNECTION_READY);
  #endif
  if (KEYBOARD_CONNECTION_READY) {
    #ifdef SERIAL_DEBUG_LOG
      Serial.println("Forwarding");
    #endif
    if (keyPressBuffer[0]!=0) {
      flushKeyboardBuffer();
    }
    if (pressed) {
      KEYBOARD_PRESS(key);
    } else {
      KEYBOARD_RELEASE(key);
    }
  } else {
    #ifdef SERIAL_DEBUG_LOG
      Serial.println("Buffering");
    #endif
    boolean foundPress = pressed; // Buffer all presses, buffer only releases with matching presses
    for (uint8_t i=0;i<32;i++) {
      #ifdef SERIAL_DEBUG_LOG
        Serial.print("Buffer slot ");
        Serial.print(i);
        Serial.print(": ");
        Serial.println((uint8_t)keyPressBuffer[i]);
      #endif
      if (!foundPress && keyPressBuffer[i]==key && (!(keyPressBufferType&(1ull<<(i-1))))==pressed) {
        foundPress = true;
      }
      if (keyPressBuffer[i]==0) {
        if (!foundPress) {
          #ifdef SERIAL_DEBUG_LOG
            Serial.println("Skipped buffering due to no press found");
          #endif
          break;
        }
        if (i>0 && keyPressBuffer[i-1]==key && (!!(keyPressBufferType&(1ull<<(i-1))))==pressed) {
          #ifdef SERIAL_DEBUG_LOG
            Serial.print("Skipped buffering: ");
            Serial.print((!!(keyPressBufferType&(1ull<<(i-1)))));
            Serial.print("/");
            Serial.println(pressed);
          #endif
          break;
        }
        keyPressBuffer[i] = key;
        keyPressBufferType &= ~(0ull<<i);
        keyPressBufferType |= ((uint32_t)pressed)<<i;
        #ifdef SERIAL_DEBUG_LOG
          Serial.print("Buffered to slot ");
          Serial.println(i);
        #endif
        break;
      }
    }
  }
}
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
void loop() {
  unsigned long startms = millis();
  #if BOARD_TYPE == ESP32
  if (bleKeyboard.isConnected()) {
  #endif
    if (readMatrix(startms-lastDebounceMs)) { // some key changed
      printMatrix();
      unstickKeys();

      // increase backlight if mic key + sym key is pressed
      if (keyActive(K_MIC) && keyPressed(K_SYM)) {
        changeKeyboardBacklight(keyboardLightSteps, keyboardLightSteps, true);
      }
      // decrease backlight if mic key + right shift key is pressed
      if (keyActive(K_MIC) && keyPressed(K_RSH)) {
        changeKeyboardBacklight(-keyboardLightSteps, -keyboardLightSteps, true);
      }

      // instant powersave mode if SYM + Enter is pressed
      if (keyActive(K_SYM) && keyPressed(K_ENTER)) {
        idleTimeout = 0;
        backlightTimeout = 0;
      }
    
      if ((keyPressed(K_LSH) && keyActive(K_RSH)) || (keyActive(K_LSH) && keyPressed(K_RSH))) {
        cursorMode = !cursorMode;
        resetStickyKeys();
      }
    } else {
      if (KEYBOARD_CONNECTION_READY && keyPressBuffer[0]!=0) {
        flushKeyboardBuffer();
      }
    }
    lastDebounceMs = startms;
    #ifdef SERIAL_DEBUG_LOG
      //Serial.print("matrix: ");
      //Serial.println(millis()-startms);
    #endif
  #if BOARD_TYPE == ESP32
  }
  #endif

  #ifdef BLINK_IN_CURSOR_MODE
    if (backlightTimeout>=millis()) {
      if (cursorMode && blinkTimeout<millis()) {
        blinkTimeout = millis() + BLINK_TIMEOUT;
        blinkState = !blinkState;
      } else if (!cursorMode) {
        blinkState = true;
      }
      changeKeyboardBacklight(0, 0, blinkState);
    }
  #endif
  #ifdef LED0_IN_CURSOR_MODE
    digitalWrite(LED0_PIN, cursorMode);
  #endif

  if (backlightTimeout<millis()) {
    #ifdef SERIAL_DEBUG_LOG
      Serial.println("Backlight off");
    #endif
    changeKeyboardBacklight(0, 0, false);
  }

  if (idleTimeout<millis()) {
    #ifdef SERIAL_DEBUG_LOG
      Serial.println("Sleep");
    #endif
    resetStickyKeys();
    firstSleep = false;
    #ifdef POWERSAVE_ARDUINO_POWERDOWN
      if (!connectionNeedsReinit1) {
        Keyboard.end();
        USBDevice.detach();
        
        //USBCON &= ~(1 << USBE);
        //USBCON |= (1 << FRZCLK);
        
        delay(300);
        connectionNeedsReinit1 = true;
      }
      LowPower.powerDown(SLEEP_15MS, ADC_OFF, BOD_OFF);
    #endif
    #ifdef POWERSAVE_ARDUINO_CLOCKDOWN
      CLKPR = 0b10000000;
      CLKPR = ARDUINO_CLOCKDOWN_DIVISION_VALUE;
      CLKPR = ARDUINO_CLOCKDOWN_DIVISION_VALUE;
      CLKPR = ARDUINO_CLOCKDOWN_DIVISION_VALUE;
      isClockedDown = true;
    #endif
    #ifdef POWERSAVE_ARDUINO_IDLE
      power_twi_disable();
      power_adc_disable();
      power_spi_disable();
      power_usart0_disable();
      power_usart1_disable();
      if (!connectionNeedsReinit1) {
        Keyboard.end();
        USBDevice.detach();
        USBCON &= ~(1 << USBE);

        delay(300);
        while (USBDevice.isSuspended()) {}
        USBCON |= (1 << USBE);
        USBDevice.attach();
        connectionNeedsReinit1 = true;
      }
      LowPower.idle(SLEEP_120MS, ADC_OFF, TIMER4_OFF, TIMER3_OFF, TIMER1_OFF, TIMER0_OFF, SPI_OFF, USART1_OFF, TWI_OFF, USB_ON);
    #endif
    #ifdef POWERSAVE_ESP32_LIGHT_SLEEP
      if (!connectionNeedsReinit1) {
        btStop();
        connectionNeedsReinit1 = true;
      }
      esp_sleep_enable_timer_wakeup(SLEEP_DURATION);
      esp_light_sleep_start();
    #endif
  }
  #ifdef POWERSAVE_ARDUINO_IDLE_DURING_ACTIVE
    if (!firstSleep) {
      LowPower.idle(SLEEP_120MS, ADC_OFF, TIMER4_OFF, TIMER3_OFF, TIMER1_OFF, TIMER0_OFF, SPI_OFF, USART1_OFF, TWI_OFF, USB_ON);
    }
  #endif
  #ifdef SERIAL_DEBUG_LOG
    //Serial.print("total:  ");
    //Serial.println(millis()-startms);
  #endif
}

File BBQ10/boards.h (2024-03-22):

#if BOARD_TYPE == FAIRBERRY_V0_1_1 || BOARD_TYPE == FAIRBERRY_V0_2_0 || BOARD_TYPE == FAIRBERRY_V0_3_0 || BOARD_TYPE == ARDUINO || BOARD_TYPE==BEETLE
  #define CHIP_TYPE CHIP_ATMEGA32U4
#elif BOARD_TYPE == ESP32
  #define CHIP_ESP32
#else
  #error "No valid BOARD_TYPE selected. Needs to be any of FAIRBERRY_V0_1_1, FAIRBERRY_V0_2_0, FAIRBERRY_V0_3_0, ARDUINO, BEETLE, ESP32"
#endif

#if defined(POWERSAVE_ARDUINO_IDLE) && defined(POWERSAVE_ARDUINO_POWERDOWN)
  #error "Cannot have POWERSAVE_ARDUINO_IDLE and POWERSAVE_ARDUINO_POWERDOWN at the same time!"
#endif

#if CHIP_TYPE != CHIP_ATMEGA32U4 && defined(POWERSAVE_ARDUINO_IDLE)
  #error "Only boards with ATMEGA32U4 chips suport POWERSAVE_ARDUINO_IDLE!"
#endif

#if CHIP_TYPE != CHIP_ATMEGA32U4 && defined(POWERSAVE_ARDUINO_POWERDOWN)
  #error "Only boards with ATMEGA32U4 chips suport POWERSAVE_ARDUINO_POWERDOWN!"
#endif

#if defined(POWERSAVE_ARDUINO_CLOCKDOWN) && !defined(ARDUINO_CLOCKDOWN_DIVISION)
  #error "ARDUINO_CLOCKDOWN_DIVISION needs to be set (to 1,2,4,8,16,32,64,128 or 256) if POWERSAVE_ARDUINO_CLOCKDOWN is enabled"
#endif

#ifdef ARDUINO_CLOCKDOWN_DIVISION
  #define ARDUINO_CLOCKDOWN_RESET_VALUE 0b00000000
  #if ARDUINO_CLOCKDOWN_DIVISION == 1
    #define ARDUINO_CLOCKDOWN_DIVISION_VALUE 0b00000000
  #elif ARDUINO_CLOCKDOWN_DIVISION == 2
    #define ARDUINO_CLOCKDOWN_DIVISION_VALUE 0b00000001
  #elif ARDUINO_CLOCKDOWN_DIVISION == 4
    #define ARDUINO_CLOCKDOWN_DIVISION_VALUE 0b00000010
  #elif ARDUINO_CLOCKDOWN_DIVISION == 8
    #define ARDUINO_CLOCKDOWN_DIVISION_VALUE 0b00000011
  #elif ARDUINO_CLOCKDOWN_DIVISION == 16
    #define ARDUINO_CLOCKDOWN_DIVISION_VALUE 0b00000100
  #elif ARDUINO_CLOCKDOWN_DIVISION == 32
    #define ARDUINO_CLOCKDOWN_DIVISION_VALUE 0b00000101
  #elif ARDUINO_CLOCKDOWN_DIVISION == 64
    #define ARDUINO_CLOCKDOWN_DIVISION_VALUE 0b00000110
  #elif ARDUINO_CLOCKDOWN_DIVISION == 128
    #define ARDUINO_CLOCKDOWN_DIVISION_VALUE 0b00000111
  #elif ARDUINO_CLOCKDOWN_DIVISION == 256
    #define ARDUINO_CLOCKDOWN_DIVISION_VALUE 0b00001000
  #endif
#endif

#if BOARD_TYPE == FAIRBERRY_V0_1_1 || BOARD_TYPE == FAIRBERRY_V0_2_0 || BOARD_TYPE == FAIRBERRY_V0_3_0
  #define F_CPU 16000000
  #define TX_RX_LED_INIT  DDRE |= (1<<6), DDRB |= (1<<0)
  #define TXLED0      PORTE |= (1<<6)
  #define TXLED1      PORTE &= ~(1<<6)
  #define RXLED0      PORTB |= (1<<0)
  #define RXLED1      PORTB &= ~(1<<0)
#endif

#if CHIP_TYPE == CHIP_ATMEGA32U4
  #if !defined(DEBUG_SERIAL_INSTEAD_OF_USB)
    #include "Keyboard.h"
  #endif
  #include "LowPower.h"
  #include <avr/power.h>

  #ifdef DEBUG_SERIAL_INSTEAD_OF_USB
    #define KEYBOARD_BEGIN(layout) Serial.begin()
    #define KEYBOARD_BEGIN(layout) ;
    #define KEYBOARD_PRESS(key) Serial.print("Pressed ");Serial.println(key);
    #define KEYBOARD_RELEASE(key) Serial.print("Released ");Serial.println(key);
  #else
    #define KEYBOARD_BEGIN(layout) Keyboard.begin(layout)
    #define KEYBOARD_END() Keyboard.end()
    #define KEYBOARD_PRESS(key) Keyboard.press(key)
    #define KEYBOARD_RELEASE(key) Keyboard.release(key)
  #endif
#elif BOARD_TYPE == ESP32
  #include "analogWrite.h"
  #define USE_NIMBLE
  #include <BleKeyboard.h>
  #include "esp_bt.h"
  #include "esp_pm.h"
  #include "esp_wifi.h"
  BleKeyboard bleKeyboard;

  #define SLEEP_DURATION 120000L
  #define KEYBOARD_BEGIN(layout) bleKeyboard.begin()
  #define KEYBOARD_END() bleKeyboard.end()
  #define KEYBOARD_PRESS(key) bleKeyboard.press(key)
  #define KEYBOARD_RELEASE(key) bleKeyboard.release(key)
#endif
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

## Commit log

2022-01-27 Case files
    [BottomOnlyCase_PLA.stl, FairberryCase.blend, TwoMaterialCase_PLA.stl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]
2022-01-27 Small fix in the cases
    [BottomOnlyCase_PLA.stl, FairberryCase.blend, TwoMaterialCase_PLA.stl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]
2022-01-27 Changed to Keyboard.h (instead of KeyboardDE.h) due to a bug in Android 11 which makes other layouts useless if you have any accessibility app active.
    [BBQ10.ino]
2022-02-01 Corrected small error in README
    a Blackberry Pro Micro - > an Arduino Pro Micro
2022-05-04 Fixed power management
2022-05-07 Moved case files to Fairphone4 subfolder
    [BottomOnlyCase_PLA.stl, FairberryCase.blend, TwoMaterialCase_PLA.stl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]
2022-05-07 Flat inline case
    [flatCase.blend, flatCase.stl]
2022-05-08 Changed Row 7 pin from 3 to A2 to free up the I2C port for possible future expansion
2022-05-09 Better powersaving options and documentation
2022-05-09 Powersaving improvements
2022-05-16 Added Hirose connector footprint
2022-05-16 Added Hirose connector footprint with shorter URL for JLCPCB
2022-08-30 Many improvements to the firmware source code, including support for different boards and a separate config file
    [configuration.h]
2022-08-30 Fairberry v0.1.1 mainboard
    [BOM_JLCSMT.xlsx, FairberryMainboard.kicad_pcb, FairberryMainboard.kicad_sch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]
2022-08-30 OpenSCAD-based script to generate the phone case parametrically
    [BBQ10KBD.blend, BBQ10KBD.stl, FP4_Dummy.stl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]
2022-10-07 Bugfix for sticky keys and reduced debug output
    [BBQ10.ino]
2022-10-09 Sticky keys and debouncing options in configuration.h
    [configuration.h]
2022-10-09 Resetting sticky keys on idle and on entering/exiting cursor mode
    [BBQ10.ino]
2022-10-09 Fixed sticky sym + ctrl -> '0'
    [BBQ10.ino]
2022-10-09 Fixed sticky SYM + ALT -> TAB
    [BBQ10.ino]
2022-10-10 Kicad files for mainboard v0.2.0
    [FairberryMainboard.kicad_pcb, FairberryMainboard.kicad_sch]
2022-10-10 Tidying up
    [BOM.xlsx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]
2022-10-10 Added v0.2.0 compatibility
    [configuration.h]
2022-10-10 Moved documentation of Arduino version into it's own file
2022-10-12 Added assembly guide
2023-01-18 Fixed debouncing
    [configuration.h]
2023-09-08 Fixed POWERSAVE_ARDUINO_POWERDOWN
2024-03-22 Hardware revision v0.3.0 (#16)
    * Split backlight into two zones, removed status LEDs, reduced y size by 1mm
    * Made firmware compatible with v0.3.0 (doesn't make use of dual backlight controls yet), refactoring
    * Improved Case Generator script, added presets for Fairphone 4 and Samsung Galaxy A54
    * Finalisation of v0.3.0 PCB
    * License/Version header for firmware
    * Removed generated stl
    [A54_Dummy.stl, BBQ10KBD.blend, BBQ10KBD.stl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]
2024-03-22 Hardware revision v0.3.0 (#16) (#19)
    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
    [A54_Dummy.stl, BBQ10KBD.blend, BBQ10KBD.stl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]
2024-03-24 Fixing keyActive/keyPressed related bugs
    [Custom.scad, Fairberry.scad]
2024-03-28 Buffer improvements
    [configuration.h]

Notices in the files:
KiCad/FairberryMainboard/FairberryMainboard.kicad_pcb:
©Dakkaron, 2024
